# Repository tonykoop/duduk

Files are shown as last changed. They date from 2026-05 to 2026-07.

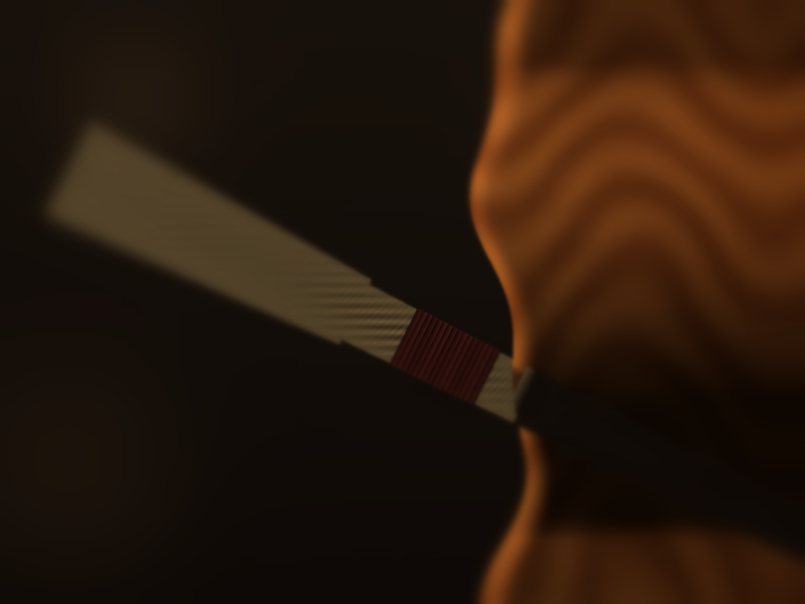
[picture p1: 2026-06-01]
images/macro/double-reed-bridle.png

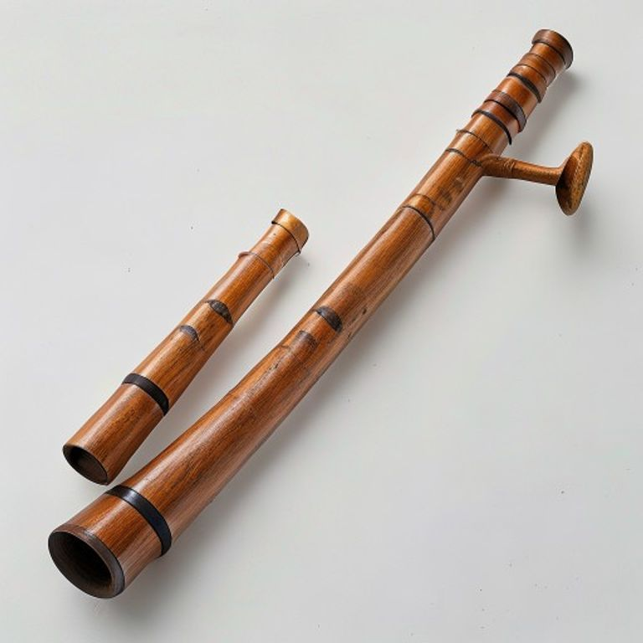
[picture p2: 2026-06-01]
images/hero-render.png

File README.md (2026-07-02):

# Duduk Family

Engineering documentation and parametric design table for the duduk family — Armenian double-reed apricot-wood instruments recognized as a UNESCO Intangible Cultural Heritage.

> **Scope.** This repository documents the geometry and acoustic physics of the duduk and its regional cousins (Turkish mey, Azerbaijani balaban, Georgian duduki) for workshop fabrication and study. It does not reproduce traditional Armenian reed-making craft or performance technique. All tuning predictions are marked **empirical** and require physical build and measurement. See [`resources.md`](resources.md) for full provenance notes.

**Status:** L1 concept packet — physical build and cultural review gates block L2 promotion. V5 surface added: family-spec.csv, visual-output-register.csv, cad/mcp-session-log.md. OpenSCAD smoke model present (pending_measurement authority). All dimensions measurement-required.

---

## Variants Documented

| Instrument | Region | Wood | Tone | Bore group |
|---|---|---|---|---|
| Duduk (*tsiranapogh*) | Armenia | Apricot | Warm, breathy, vocal | 0.315–0.551″ |
| Mey | Turkey | Plum / walnut | Bright, nasal | 0.394–0.630″ |
| Balaban | Azerbaijan | Mulberry | Reedy, penetrating | 0.315–0.551″ |
| Duduki | Georgia | Apricot/similar | Narrow, focused | 0.315–0.472″ |

20 keys documented (E3–B4 root) across all variants.

## Primary Build Target

**Armenian Duduk, A3 root** (traditional concert size)

| Parameter | Value | Status |
|---|---|---|
| Bore ID | 0.472″ / 12.0 mm | design input |
| Wall | 0.138″ / 3.5 mm | design input |
| OD | 0.748″ / 19.0 mm | calculated |
| Body length | ≈ 13.25″ / 33.7 cm | *EMPIRICAL* |
| Reed | Arundo donax, 3.90″ × 0.63″ | traditional |
| Wood | Apricot (preferred); walnut (alternate) | — |

Acoustic model: stopped cylindrical pipe, `f = c / (4·L_eff)`. Scale: A natural minor.

## Packet Contents

```
duduk/
├── README.md                   ← this file
├── duduk-design-table.xlsx     ← parametric design sheet (20 keys × 4 variants)
├── design.md                   ← acoustic model, hole schedule, family table
├── bom.csv                     ← bill of materials
├── sourcing.csv                ← supplier guidance
├── cut-list.csv                ← stock and machining sizes
├── validation.csv              ← dimensional and tuning checks
├── reed-bore-authority-gates.csv ← reed and bore promotion gates (R35b)
├── assembly-manual.md          ← step-by-step build instructions
├── supplier-rfq.md             ← RFQ template
├── visual-bom-brief.md         ← visual BOM spec
├── drawing-brief.md            ← drawing package spec
├── photo-shotlist.md           ← photo documentation plan
├── risks.md                    ← red-team risk register
├── resources.md                ← provenance, sources, cultural context
├── jig-decision.md             ← fixture decisions
├── explorer.html               ← studio explorer for packet review
├── drawings/
│   └── duduk-a3-section.svg   ← dimensioned longitudinal cross-section
├── cnc/
│   └── setup-sheet.md         ← lathe + drill-press operation plan
├── wolfram/
│   └── wolfram-starter.wl     ← Wolfram acoustic model package
├── site/
│   └── index.html             ← build-log static site
├── cad/                        ← conservative OpenSCAD smoke starter + CAD notes
├── evolution/                   ← evolution-pipeline Stage 0 intake: master manifest, design-intent, revision register (Gate A not yet run)
├── images/                     ← (placeholder — photos per photo-shotlist.md)
└── data/                       ← (placeholder — measured validation data)
```

## Quick Start

1. Read [`design.md`](design.md) for the acoustic model and empirical caveats.
2. Open `duduk-design-table.xlsx` (Sheet: Duduk Family) for the full parametric table.
3. Open [`explorer.html`](explorer.html) for a review-friendly index of the design files, validation gates, Wolfram source, print packet, site, and songbook material.
4. Order materials per [`sourcing.csv`](sourcing.csv) — **order 6+ reeds**; reed quality dominates the build outcome.
5. Follow [`assembly-manual.md`](assembly-manual.md) — body length is set empirically during reed fitting, not by formula.
6. Record all measured values in [`validation.csv`](validation.csv).
7. Review [`risks.md`](risks.md) — pay special attention to RISK-AC-01 (body length) and RISK-SC-02 (reed quality).
8. Before promoting any reed spec, bore dimension, calibrated body length, or fabrication DXF, clear the relevant rows in [`reed-bore-authority-gates.csv`](reed-bore-authority-gates.csv). The OpenSCAD smoke artifact in `cad/` and the dimensional starters in `design.md` are not fabrication authority until those gates pass.

## Cultural Heritage

The Armenian duduk (*tsiranapogh* — "apricot pipe") is a UNESCO Intangible Cultural Heritage instrument (2005). It is central to Armenian ceremonial music, played at weddings, funerals, and church services. The traditional knowledge of reed-making and performance practice is passed orally within the Armenian musical community.

This repository documents engineering geometry only. For the living musical tradition, listen to master players such as Djivan Gasparyan, and seek instruction from Armenian musicians.

See [`resources.md`](resources.md) for a full cultural context statement, source list, and public-release checklist.

## License

[CC BY 4.0](LICENSE) — engineering documentation. Cultural knowledge and traditional technique belong to the communities that carry them.

---

Part of the [tonykoop/instrument-maker](https://github.com/tonykoop/instrument-maker) catalogue · Generated with instrument-maker-v4.3

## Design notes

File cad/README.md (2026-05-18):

# Duduk CAD Starter

No build-ready CAD solids are included yet.
This lane ships a conservative OpenSCAD smoke artifact for visualization only:

- `duduk-openscad-smoke.scad`

Model the first body only after the A3-root prototype is measured with the reed actually used for tuning.

## Suggested Parameters

- `bore_id = 0.472 in`
- `body_od = 0.748 in`
- `body_length = measured after reed fit`
- `hole_positions = measured/tuned values from validation.csv`
- `reed_socket_depth = measured for selected reed`

## Notes

Keep the CAD file marked empirical until the reed/body calibration is complete. Duduk body length and hole behavior are reed-dependent, so workbook estimates should seed the model rather than freeze it.

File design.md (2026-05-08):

# Duduk Family — Design Document

**v4.3 Root-Mode Packet** | Generated 2026-05-08 | Status: DRAFT — Empirical Pending Build

> **Provenance Notice.** The duduk (dooduk / tsiranapogh) is an Armenian double-reed instrument recognized as a UNESCO Intangible Cultural Heritage (2005). This document is engineering reference material for study and workshop fabrication. It does not attempt to reproduce traditional performance technique, reed-making craft, or the tonal qualities achieved by master makers. Dimensions here are derived from published organological sources and cannot substitute for an instrument made by or studied with a traditional craftsperson. All acoustic predictions are first-estimate only and must be validated by physical build and tuning measurement. See `resources.md` for provenance, source citations, and cultural context.

---

## 1. Instrument Identity

| Field | Value |
|---|---|
| Instrument family | Duduk / Balaban / Mey (cylindrical-bore double-reed) |
| Primary variant documented | Armenian Duduk (*tsiranapogh* — apricot pipe) |
| UNESCO ICH status | 2005 (Armenian duduk and its music) |
| Acoustic class | Closed cylindrical aerophone (stopped pipe) |
| Excitation | Giant double reed (Arundo donax), sub-resonant to bore |
| Bore profile | Cylindrical (slight practical taper in traditional instruments — modeled as cylinder here) |
| Key naming convention | Instrument named root+3 semitones (e.g., "A3-root" instrument = "C4 duduk" by key name) |
| Design sheet | `duduk-design-table.xlsx` — Sheet: Duduk Family |
| Primary example | A3-root Armenian Duduk (bore 0.472″, OD 0.748″) |

---

## 2. Regional Variants

Four variants are documented in `duduk-design-table.xlsx`. All share the stopped-pipe acoustic model and 9-hole layout; they differ in bore diameter, wall thickness, reed dimensions, and traditional wood species.

| Variant | Wood | Tone character | Bore group (large/mid/small) |
|---|---|---|---|
| Armenian Duduk (*tsiranapogh*) | Apricot (*Prunus armeniaca*) | Warm, breathy, voice-like | 0.551″ / 0.472″ / 0.394″ / 0.315″ |
| Turkish Mey | Plum or walnut | Bright, nasal | 0.630″ / 0.551″ / 0.472″ / 0.394″ |
| Azerbaijani Balaban | Mulberry | Reedy, penetrating | 0.551″ / 0.472″ / 0.394″ / 0.315″ |
| Georgian Duduki | Apricot or similar | Similar to Armenian, narrower | 0.472″ / 0.394″ / 0.354″ / 0.315″ |

---

## 3. Governing Acoustic Model

### 3.1 Stopped Cylindrical Pipe

The duduk bore is modeled as a closed-open cylindrical pipe:

```
f_n = c · (2n − 1) / (4 · L_eff)      n = 1, 2, 3, …
```

- `f_1` (fundamental): `f = c / (4 · L_eff)`
- `c` = 343.0 m/s = 13,503.9 in/s at 20 °C / 68 °F
- Odd harmonics only → mellow, clarinet-like timbre

### 3.2 Effective Length

```
L_eff = L_body + L_reed_eff − δ_open_end
```

| Term | Symbol | Value (A3 primary) | Notes |
|---|---|---|---|
| Body tube length | `L_body` | **13.25″ / 33.7 cm** | *EMPIRICAL ESTIMATE — pending build* |
| Reed effective length | `L_reed_eff` | **1.95″ / 4.95 cm** | *~0.5 × physical reed — EMPIRICAL* |
| Open-end correction | `δ` | 0.142″ / 0.36 cm | `0.6 × r_bore` |
| Total acoustic length | `L_eff` | 15.35″ / 39.0 cm | c/(4×220 Hz) |

> **⚠ Empirical guard.** The reed effective length is the largest source of uncertainty. Traditional makers tune `L_body` empirically against the reed in use. The 0.5× estimate is a starting point only. Expect to trim the body or adjust the reed insert depth after first assembly. Record measured values in `validation.csv`.

### 3.3 End Correction (Workbook Formula)

From the embedded Wolfram spec in `duduk-design-table.xlsx`:

```mathematica
lDuduk[f_, bore_] := 343/(4 f) - 0.6 bore   (* SI units, bore = radius in meters *)
```

Where `bore` = bore radius (meters). This gives open-end correction = `0.6 × r_bore`.

### 3.4 Reed Sub-Resonance Requirement

The duduk double reed must be *sub-resonant* to the bore: the reed's natural vibration frequency must be higher than the bore's fundamental. If reed pitch < bore pitch, the instrument will not stable-oscillate on the fundamental.

```
f_reed_natural > f_bore_fundamental
```

- Players adjust reed pitch via the **bridle** (a band that constrains reed opening). Squeezing the bridle → reed natural frequency rises → instrument plays sharper.
- Reed pitch is controlled by bridle tightness, soaking duration, and temperature.
- **This is not predictable from geometry alone.** Reed behavior is EMPIRICAL.

Approximate reed cavity estimate (heuristic only):

```
f_reed_approx ≈ 0.6 × c / (2 × L_reed_physical)
```

For A3-root reed (3.9″ = 0.099 m): `f_reed_approx ≈ 0.6 × 343 / (2 × 0.099) ≈ 1040 Hz`
→ Well above 220 Hz bore fundamental. Sub-resonance condition likely satisfied. **Verify by ear on first build.**

### 3.5 Tone-Hole Positions — Simplified Cutoff Estimate (EMPIRICAL)

The table below uses a simplified acoustic cutoff approximation:
`position_from_bell ≈ L_acoustic(fundamental) − L_acoustic(hole_note)`

This is a **first estimate only**. Actual positions depend on tone-hole diameter, undercutting, and the tone-hole lattice interaction. All values require physical verification.

**A3-root Armenian Duduk — Hole Schedule (EMPIRICAL ESTIMATES)**

| Hole | Finger | Note | Freq (Hz) | Est. position from bell | Est. position from bell | Status |
|---|---|---|---|---|---|---|
| Root | all closed | A3 | 220.00 | — | — | model anchor |
| 1 | RH pinky | B3 | 246.94 | 1.67″ | 4.25 cm | *EMPIRICAL* |
| 2 | RH ring | C4 | 261.63 | 2.44″ | 6.20 cm | *EMPIRICAL* |
| 3 | RH middle | D4 | 293.66 | 3.85″ | 9.78 cm | *EMPIRICAL* |
| 4 | RH index | E4 | 329.63 | 5.10″ | 12.96 cm | *EMPIRICAL* |
| 5 | LH ring | F4 | 349.23 | 5.68″ | 14.42 cm | *EMPIRICAL* |
| 6 | LH middle | G4 | 392.00 | 6.73″ | 17.10 cm | *EMPIRICAL* |
| 7 | LH index | A4 | 440.00 | 7.67″ | 19.49 cm | *EMPIRICAL* |
| 8 | top front | B4 | 493.88 | 8.51″ | 21.61 cm | *EMPIRICAL* |
| 9 | thumb | C5 | 523.25 | 8.89″ | 22.59 cm | *EMPIRICAL* |

Scale: A natural minor (Aeolian) — A B C D E F G A.
Duduk repertoire frequently uses microtonal and modal inflections not captured here.

---

## 4. Primary Instrument Specification — Armenian Duduk, A3 Root

All dimensions marked **EMPIRICAL** are first estimates pending physical build and measurement.

| Parameter | Value | Status |
|---|---|---|
| Root note (all-closed fundamental) | A3 | design anchor |
| Duduk key name (root + 3 semitones) | C4 | convention |
| Frequency | 220.00 Hz | target |
| Bore ID | **0.472″ / 12.0 mm** | design input |
| Wall thickness | **0.138″ / 3.5 mm** | design input |
| Outer diameter | **0.748″ / 19.0 mm** | = bore + 2×wall |
| Body length (tube only) | **≈ 13.25″ / 33.7 cm** | *EMPIRICAL* |
| Reed insert socket depth | **≈ 0.50″ / 12.7 mm** | TBD |
| Reed physical length | 3.90″ / 99 mm | design input |
| Reed physical width | 0.63″ / 16 mm | design input |
| Reed material | Arundo donax (giant cane) | traditional |
| Wood species | Apricot (*Prunus armeniaca*) | traditional |
| Wood alternative | Walnut, mulberry, cherry | non-traditional |
| Tone holes | 9 (8 front + 1 thumb) | design |
| Hole diameter (estimate) | ≈ 0.25″ / 6.35 mm | *EMPIRICAL — adjust for ergonomics* |
| Bell end | open (no bell flare) | design |

---

## 5. Full Family Body Length Table — Armenian Duduk

All body-length values are **EMPIRICAL ESTIMATES** from the stopped-pipe formula minus estimated reed effective length. Physical reeds will vary; trim to tune.

| Key name | Root | Freq | Bore ID | OD | Reed L | Body est. | Body est. |
|---|---|---|---|---|---|---|---|
| Eb3 | E3 | 164.81 Hz | 0.551″ | 0.865″ | 4.70″ | **≈ 17.97″** | ≈ 45.6 cm |
| F3 | F3 | 174.61 Hz | 0.551″ | 0.865″ | 4.70″ | **≈ 16.82″** | ≈ 42.7 cm |
| Gb3 | Gb3 | 185.00 Hz | 0.551″ | 0.865″ | 4.70″ | **≈ 15.73″** | ≈ 40.0 cm |
| Ab3 | G3 | 196.00 Hz | 0.551″ | 0.865″ | 4.70″ | **≈ 14.71″** | ≈ 37.4 cm |
| A3 | Ab3 | 207.65 Hz | 0.551″ | 0.865″ | 4.70″ | **≈ 13.74″** | ≈ 34.9 cm |
| **C4** | **A3** | **220.00 Hz** | **0.472″** | **0.748″** | **3.90″** | **≈ 13.25″** | **≈ 33.7 cm** |
| Db4 | Bb3 | 233.08 Hz | 0.472″ | 0.748″ | 3.90″ | **≈ 12.39″** | ≈ 31.5 cm |
| Eb4 | B3 | 246.94 Hz | 0.472″ | 0.748″ | 3.90″ | **≈ 11.58″** | ≈ 29.4 cm |
| E4 | C4 | 261.63 Hz | 0.472″ | 0.748″ | 3.90″ | **≈ 10.81″** | ≈ 27.5 cm |
| F4 | Db4 | 277.18 Hz | 0.472″ | 0.748″ | 3.90″ | **≈ 10.09″** | ≈ 25.6 cm |
| G4 | D4 | 293.66 Hz | 0.394″ | 0.630″ | 3.50″ | **≈ 9.63″** | ≈ 24.5 cm |
| Ab4 | Eb4 | 311.13 Hz | 0.394″ | 0.630″ | 3.50″ | **≈ 8.98″** | ≈ 22.8 cm |
| A4 | E4 | 329.63 Hz | 0.394″ | 0.630″ | 3.50″ | **≈ 8.37″** | ≈ 21.3 cm |
| Bb4 | F4 | 349.23 Hz | 0.394″ | 0.630″ | 3.50″ | **≈ 7.80″** | ≈ 19.8 cm |
| B4 | Gb4 | 369.99 Hz | 0.394″ | 0.630″ | 3.50″ | **≈ 7.26″** | ≈ 18.4 cm |
| C5 | G4 | 392.00 Hz | 0.315″ | 0.511″ | 3.50″ | **≈ 6.77″** | ≈ 17.2 cm |
| Db5 | Ab4 | 415.30 Hz | 0.315″ | 0.511″ | 3.50″ | **≈ 6.29″** | ≈ 15.9 cm |
| D5 | A4 | 440.00 Hz | 0.315″ | 0.511″ | 3.50″ | **≈ 5.83″** | ≈ 14.8 cm |
| Eb5 | Bb4 | 466.16 Hz | 0.315″ | 0.511″ | 3.50″ | **≈ 5.40″** | ≈ 13.7 cm |
| E5 | B4 | 493.88 Hz | 0.315″ | 0.511″ | 3.50″ | **≈ 4.99″** | ≈ 12.7 cm |

**Bold row** = primary build target.

---

## 6. Design Notes and Open Questions

1. **Reed effective length (critical unknown).** The 0.5× factor is a rough heuristic. Traditional makers tune body length empirically with the reed in hand. Plan to build at +0.5″ over estimate and trim. Record final length in `validation.csv`.

2. **Bore taper.** Real Armenian duduks have a slight practical taper (wider at bell, narrower at reed end). This model treats it as perfectly cylindrical. Taper affects harmonic structure and tone color but has second-order effect on fundamental pitch. Treat as post-build refinement.

3. **Hole diameter and undercutting.** Tone-hole diameters affect cutoff frequency and cross-fingering possibilities. Starting estimate 0.25″; adjust for player hand size and desired response. Undercutting is a traditional technique to widen effective diameter without enlarging the surface opening.

4. **Scale accuracy.** The A natural minor scale holes give diatonic Armenian repertoire access. Traditional duduk playing uses extensive microtonal inflection via partial hole closure and embouchure — this cannot be captured in a fixed-hole layout.

5. **Reed sourcing.** Traditional Arundo donax reeds for duduk are specialty items. Source from Armenian or Middle Eastern music suppliers. Plan 4–6 reeds for initial testing (they break during adjustment). See `sourcing.csv` and `resources.md`.

6. **Wood species.** Apricot is the traditional and acoustic-preferred species but is not commonly available in US lumber yards. Walnut is a reasonable substitute (similar density, ρ ≈ 640–700 kg/m³ vs apricot ≈ 750 kg/m³). Will produce different tone color — do not claim tonal equivalence with traditional instruments.

7. **Authenticity scope.** This packet documents the geometry and physics of the duduk for workshop fabrication. Producing an instrument that approaches traditional performance quality requires additional study of Armenian reed-making and playing technique. See `resources.md`.

---

## 7. File Map

| File | Contents |
|---|---|
| `design.md` | This document |
| `duduk-design-table.xlsx` | Parametric design sheet (20 keys × 4 variants) |
| `bom.csv` | Bill of materials — A3-root Armenian build |
| `sourcing.csv` | Supplier recommendations |
| `cut-list.csv` | Stock and machining sizes |
| `validation.csv` | Tuning and dimensional check sheet |
| `assembly-manual.md` | Step-by-step build instructions |
| `supplier-rfq.md` | RFQ template for wood stock and reeds |
| `visual-bom-brief.md` | Visual BOM layout spec |
| `drawing-brief.md` | Drawing package spec |
| `wolfram/wolfram-starter.wl` | Wolfram model package |
| `drawings/duduk-a3-section.svg` | Dimensioned cross-section drawing |
| `cnc/setup-sheet.md` | CNC/lathe operation plan |
| `risks.md` | Red-team risk register |
| `resources.md` | Provenance, sources, cultural context |
| `jig-decision.md` | Fixture and jig decisions |
| `photo-shotlist.md` | Photo documentation plan |
| `site/index.html` | Build-log static site |

---

*Generated by instrument-maker-v4.3. All EMPIRICAL values require physical measurement before this packet is considered verified.*

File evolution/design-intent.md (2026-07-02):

# Design Intent — duduk rev A

- Master CAD: `cad/duduk-openscad-smoke.scad` (sha256: 5170423d3b3888ee2061eca8edef346e37ca6009c16b8273b03ef496fd137f22), driven by `duduk-design-table.xlsx` (sha256: e925b761a699e7a820cd903535036578964f6b31b38beb67a34fb77ca904b2b1)
- Function: Closed cylindrical stopped-pipe aerophone (Armenian duduk / Turkish mey / Azerbaijani balaban / Georgian duduki variants) excited by a giant double reed (Arundo donax), sub-resonant to the bore. 9-hole layout per variant; body length is an acoustic-model estimate pending reed-fit trim. UNESCO ICH (2005) — engineering reference only, not a claim of cultural/performance reproduction (see resources.md).
- Environment: hand-held wind instrument; wood body moves with humidity/oiling; reed behavior (and thus true body length) depends on the specific reed used.
- Target qty: 1 (prototype, A3-root Armenian variant). Deadline: TBD. Budget/unit ceiling: TBD.

## Critical dimensions (carry tolerances)

| Feature | Nominal | Tolerance | Why critical | Source |
| --- | --- | --- | --- | --- |
| Bore ID (A3 Armenian) | 0.472 in | ±0.005 in (validation.csv V-DIM-01) | tuning/timbre | family-spec.csv DUD-ARM-A3 (design_table_backed) |
| Body OD | 0.748 in | ±0.005 in (V-DIM-02) | wall strength vs. tone | duduk-design-table.xlsx (design_table_backed) |
| Wall thickness | 0.138 in | inspect for splitting (risks.md RISK-ST-01) | structural, thin-wall drilling risk | family-spec.csv (design_table_backed) |
| Body length (tube) | 13.25 in (estimate) | trim incrementally to tuned pitch (V-DIM-03) | intonation, reed-dependent | family-spec.csv (measurement_required) |
| Reed physical length | 3.90 in | ±0.10 in (V-DIM-04) | sub-resonance condition | bom.csv DUD-A3-002 (measurement_required) |
| Hole positions (1-9) | per simplified cutoff formula | ±30 cents initial, ±15 cents target (RISK-AC-03) | intonation, cannot un-drill | design.md governing model (measurement_required) |

## Incidental (free for DFM)

- Exterior finish choice (tung oil/wax), reed bridle material (thread vs. heat-shrink), cosmetic body taper/shaping outside the bore.

## Must-nots (DFM may never violate)

- Never drill side-force on the bore; drill-press only, perpendicular to bore axis (risks.md RISK-ST-01).
- Do not treat hole positions as final until each is drilled-and-tested in order from bell-end up, per RISK-AC-03.
- Do not publish or promote this packet as a cultural reproduction; it is workshop engineering reference only — cultural-review gates block L2 promotion (README, resources.md).
- Do not treat the four regional variants (Armenian/Mey/Balaban/Duduki) as interchangeable in public-facing text (RISK-AC/resources.md).
- Body length in family-spec.csv is an acoustic estimate, not a cut dimension — build over-length and trim per RISK-AC-01.

## Material intent

- Preferred: apricot wood (traditional, Armenian variant) or walnut/plum/mulberry per variant, per bom.csv.
- Acceptable subs: per bom.csv Source Category notes (specialty lumber/turning blank suppliers).
- Forbidden: film-forming finish on the bore (bom.csv DUD-A3-005 note); only food-safe bore oil.

## Stage status

Stage 0 intake complete 2026-07-01. Gate A (Alpha shop compile) NOT yet run — no concessions logged, nothing presented as shippable. Physical build and cultural review gates remain open per README; this intake does not change that.

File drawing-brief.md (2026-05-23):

# Drawing Brief — Duduk Family

**Drawing package:** Armenian Duduk, A3 root — v4.3 draft
**Date:** 2026-05-08
**File:** `drawings/duduk-a3-section.svg` (generated)

---

## Drawings Required

### DWG-01 — Body Cross-Section (primary)

- **View:** Longitudinal section through bore centerline
- **Scale:** 1:1 at A4/letter, or 1:2 if body won't fit at 1:1
- **Datum:** Bell end = 0 reference
- **Show:**
  - Outer profile (OD = 0.748″)
  - Bore (ID = 0.472″)
  - Wall thickness (0.138″ each side)
  - Tone hole positions (Holes 1–9, from bell) — marked EMPIRICAL
  - Tone hole diameters (~0.250″ est.) — marked EMPIRICAL
  - Reed socket depth (~0.500″) — marked TBD
  - Body length (≈ 13.25″ est.) — marked EMPIRICAL
  - Total acoustic length reference (15.35″ incl. reed eff.)
- **Title block:** Instrument, key, date, version, "EMPIRICAL — verify before drilling"
- **Material note:** Apricot / walnut, bore oil finish
- **Units:** Inches primary, cm secondary in parentheses

### DWG-02 — Hole Schedule (table drawing)

- **Format:** Table embedded in SVG or separate sheet
- **Columns:** Hole ID | Finger | Note | Freq (Hz) | Position from bell (in) | Position from bell (cm) | Dia (in) | Status
- **All positions flagged:** "EMPIRICAL ESTIMATE — measure and record actual in validation.csv"

### DWG-03 — Reed Geometry (reference)

- **View:** Side view of double reed showing overall length, tip width, shank width
- **Dimensions:** 3.90″ L × 0.63″ tip width, shank ≈ OD of bore
- **Note:** "Reed is not manufactured in-house. Dimensions shown for reference matching only."
- **Cross-section:** Flattened elliptical cross-section at tip; circular at shank

### DWG-04 — Family Comparison (optional, later)

- **View:** Side elevation of 4 variants (A3 Armenian, Turkish Mey, Balaban, Georgian) at same scale
- **Purpose:** Shows relative sizes across the family

---

## Drawing Standards

- All critical dimensions boxed
- Tolerance notes: ±0.005″ bore ID; ±0.005″ OD; hole positions ±0.020″ (first pass — adjust empirically)
- Revision block with date
- "DRAFT — v4.3 — Not for production without physical validation" watermark
- Title block: Instrument name | Key | Variant | Scale | Date | Drawn by

---

## Promotion Authority

Before any of the above drawings is promoted from EMPIRICAL/DRAFT to a fabrication-authority DXF, STEP, or shop-reviewed CAD release, check `reed-bore-authority-gates.csv`:

- DWG-01 bore ID, OD, wall, and body length are blocked by `BORE-GATE-001` (bore ID 3-point measurement), `BORE-GATE-002` (cylindricity / taper), and `BORE-GATE-003` (calibrated body length after empirical reed trim).
- DWG-01 reed socket depth and DWG-03 reed geometry are blocked by `REED-GATE-001` (reed dimensional spec), `REED-GATE-003` (reed effective length), and `REED-GATE-004` (reed stability under bridle).
- A full fabrication DXF or STEP is blocked by `BORE-GATE-004` until all preceding gates clear.

The existing `drawings/duduk-a3-section.svg` and the `cad/duduk-openscad-smoke.scad` smoke artifact remain draft/illustrative and do not satisfy these gates.

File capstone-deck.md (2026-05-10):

# Slide 1 - Duduk Family

L2 engineering packet for Armenian duduk and related mey, balaban, and duduki geometry.

# Slide 2 - Project Intent

Document a cautious shop prototype path for a reed-dependent heritage instrument while keeping empirical, cultural, and validation gaps explicit.

# Slide 3 - Cultural Scope

This packet covers engineering geometry only. It does not claim to reproduce Armenian reed-making, performance practice, or tonal tradition.

# Slide 4 - Governing Model

Stopped cylindrical pipe, `f = c/(4*L_eff)`, with reed effective length and open-end correction treated as empirical.

# Slide 5 - Primary Target

A3-root Armenian duduk body, 0.472 in bore ID, 0.748 in OD, approximate 13.25 in body length before reed calibration.

# Slide 6 - Packet Files

Design, BOM, sourcing, cut list, validation, assembly, drawing brief, SVG section, Wolfram starter, risks, resources, and site are present.

# Slide 7 - Manufacturing Plan

Turn and bore the body, fit reed socket, source multiple reeds, then tune body length and holes against the selected reed.

# Slide 8 - Validation

Validation centers on bore dimensions, reed fit, all-closed A3, every tone hole, reed stability, and cultural review before public release.

# Slide 9 - Risks

Top risks are reed effective length error, unverified hole positions, reed quality, and overclaiming cultural authenticity.

# Slide 10 - Sourceability

Apricot wood and duduk reeds require supplier verification. Current prices and availability are not checked.

# Slide 11 - Readiness

L2 private draft. Not public-ready until build photos, measured validation, and cultural review are complete.

# Slide 12 - Next Actions

Verify reed/wood sources, fit test reeds, build A3 body with trim allowance, populate validation.csv, then revisit CAD and public release.

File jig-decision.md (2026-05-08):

# Jig and Fixture Decision Log — Duduk Family

**v4.3** | 2026-05-08
Documents fixture choices for turning, boring, and hole-drilling operations on the duduk body.

---

## JIG-01 — Bore Drilling: Tailstock / Drill-Press Decision

**Question:** Should the bore be drilled on the lathe (tailstock-mounted drill) or on the drill press?

**Decision: Lathe (tailstock), using a long-series Forstner or D-bit.**

**Rationale:**
- The body blank is a cylinder ≤ 1.00″ dia × 16″ L. Holding it in a drill-press vise while drilling a 0.472″ bore 14″ deep is difficult to keep on-axis.
- On the lathe, the blank is already centered and rotating; the bit advances straight into the rotating stock. This is the conventional approach for cylindrical instrument bores.
- Drill-press boring requires a long-series bit, a reliable V-block or chuck, and very careful alignment — viable but harder than lathe boring for this geometry.

**Tooling selected:**
- **0.472″ long-series Forstner bit** (preferred for clean entry and flat bottom)
- Backup: **0.472″ D-bit or brad-point** for deeper runs where Forstner chatter may occur

**Setup notes:**
- Lathe speed: 300–500 RPM (slow for long boring)
- Back out every 0.5″ to clear chips
- Use cutting fluid (beeswax or dry lube on bit shank) to reduce heat buildup
- Check bore straightness with a light source at the open end after boring

**Verification:** After boring, measure bore ID with calipers at 3 points (near reed end, mid, near bell). Variation > 0.010″ = investigate re-centering.

---

## JIG-02 — Tone-Hole Drilling: V-Block Alignment Jig

**Question:** How to hold the finished cylinder for accurate perpendicular tone-hole drilling?

**Decision: V-block jig on drill press, with a registration stop for datum from bell end.**

**Rationale:**
- Tone holes must be perpendicular to the bore axis and at accurate positions along the body length.
- The finished body is a smooth cylinder — prone to rolling on a flat drill-press table.
- A V-block constrains the cylinder and keeps the drill axis perpendicular to the bore centerline.
- A registration stop (a wooden block clamped to the V-block) referenced from the bell end sets the datum for measuring hole positions.

**Jig construction:**
- V-block: 2×4 lumber with a 90° V-groove routed or cut to accept the 0.748″ OD. Groove depth ≈ 0.375″.
- Length: 12″ to support the full body.
- Stop block: a small wooden block clamped or screwed at the bell-end datum position. The bell face of the body registers against this stop.
- Clamp the cylinder with a soft strap or tape — do not over-clamp (crushes wood).

**Hole marking procedure:**
1. Seat body in V-block with bell end against stop.
2. Mark all 9 hole center positions along the top of the cylinder from bell-end datum (positions per `design.md` Section 3.5 — mark with Dykem + scribe).
3. Use a small center-punch or awl to create a dimple at each mark (prevents drill walk).
4. Drill pilot hole 0.1875″ first; open to 0.250″ in second pass.
5. Move stop registration only if re-measuring from bell — do not disturb mid-sequence.

**Verification:** After marking all centers, check spacing with calipers vs design table. Re-mark if any position is off by > 0.030″ before drilling.

---

## JIG-03 — Reed Shank Fitting: No Jig Required

**Question:** Does fitting the reed into the socket require a fixture?

**Decision: No dedicated jig — PTFE tape wrapping is hand-fitted.**

**Rationale:**
- The reed socket is simply the bore opening at the reed end of the body.
- Fitting is accomplished by wrapping the reed shank with PTFE plumber's tape until it seats firmly with a light press-fit.
- No precision fixture is needed; this is a common technique for woodwind reed fitting.
- The reed's position (depth of insertion) is adjusted empirically to tune the instrument.

**Procedure:**
1. Soak reed 15 minutes. Mount no PTFE yet.
2. Insert reed shank dry into bore top — feel how loose the fit is.
3. Wrap 3–5 layers of PTFE tape around the shank.
4. Re-insert — should seat firmly with light thumb pressure, no rocking.
5. Mark the seating depth with a pencil mark on the reed shank.
6. If too loose: add 1–2 more PTFE layers. If too tight: remove 1 layer.

---

## JIG-04 — Reaming / Bore Finishing: Dowel Sanding Mandrel

**Question:** How to sand the bore interior smooth after drilling without a reamer?

**Decision: Homemade sanding mandrel from a close-fitting wooden dowel.**

**Rationale:**
- A commercial adjustable reamer for 0.472″ is available but expensive for a one-off build.
- A dowel slightly undersized (0.440–0.460″ dia) wrapped with sandpaper is adequate for smoothing tearout after boring.
- This is suitable for finishing but not for enlarging the bore; all primary sizing must be done by the drill bit.

**Construction:**
- Turn or purchase a hardwood dowel 0.450″ dia × 12″ L.
- Wrap with 120/180/220/320 grit sandpaper (cut strips, spiral-wrap, secure with tape at ends).
- Chuck in lathe or spin by hand for lapping action.

**Verification:** Bore should feel smooth to a cotton swab drawn through it. No snagging or roughness.

---

## Jig Priority Summary

| Jig | Necessity | Build effort | When needed |
|---|---|---|---|
| JIG-01 Lathe setup | Required | Lathe chuck/centers (existing) | Before boring |
| JIG-02 V-block hole drill jig | Required | 1–2 hrs shop time | Before tone holes |
| JIG-03 PTFE fitting | Not a jig — hand technique | None | Reed fitting |
| JIG-04 Sanding mandrel | Recommended | 30 min | After boring |

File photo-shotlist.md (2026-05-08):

# Photo Shot List — Duduk Family Build

**Date:** 2026-05-08 | **Instrument:** Armenian Duduk, A3 root

Follow Tony's photo-pipeline standards: `docs/photo-pipeline.md` (in instrument-maker repo).
All photos for the build log must show actual instrument/parts — no stock images.

---

## Pre-Build

| Shot | Description | Setup | Notes |
|---|---|---|---|
| PB-01 | Raw wood blank | White card + natural light | Show grain direction; annotate OD |
| PB-02 | Reed (before fitting) | White card + macro lens | Show tip, bridle, shank; include 6" rule for scale |
| PB-03 | All materials laid out | Flat-lay on workbench | BOM shot: body blank, reeds, bridle, oils |

## During Build (In-Shop)

| Shot | Description | Setup | Notes |
|---|---|---|---|
| SH-01 | Blank mounted on lathe (before boring) | In-shop, tool visible | Show setup clearly |
| SH-02 | Boring operation (mid-drill) | In-shop | Capture chips, tooling |
| SH-03 | Bore after drilling — light through bore | End-on, backlit | Shows bore straightness (or lack thereof) |
| SH-04 | OD turning — tool at cut | In-shop | |
| SH-05 | Bore oiling — applying linseed | Close-up | Show application method |
| SH-06 | Hole marking — layout dye + scribe | Close-up | Show datum reference from bell end |
| SH-07 | Drilling first tone hole on drill press | In-shop | Show V-block jig setup |
| SH-08 | Reed fitting — PTFE wrap on shank | Close-up | |
| SH-09 | Tuning check — tuner reading fundamental | In-shop | Capture tuner display showing ~A3 |

## Finished Instrument

| Shot | Description | Setup | Notes |
|---|---|---|---|
| FIN-01 | Full instrument — front view | White card or neutral background | Horizontal, 3/4 angle |
| FIN-02 | Full instrument — side view | Same setup | |
| FIN-03 | Bell end close-up | Macro | Show bore and end grain |
| FIN-04 | Reed end with reed inserted | Macro | Show bridle and reed-bore junction |
| FIN-05 | All 9 holes visible | Angled | Light from side to show holes clearly |
| FIN-06 | Thumb hole — back side | Macro | |
| FIN-07 | Player holding instrument | In-use | Right-hand-down, left-hand-up conventional grip |
| FIN-08 | All family variants together (future) | Flat-lay | Once multiple keys are built |

## Details

| Shot | Description |
|---|---|
| DET-01 | Grain pattern — exterior close-up |
| DET-02 | Wall cross-section if a scrap was parted off |
| DET-03 | Reed tip — extreme macro showing cane cell structure |
| DET-04 | Bridle adjustment detail |

---

*Minimum for site/build-log: PB-03, SH-01, SH-07, SH-09, FIN-01, FIN-04, FIN-05.*
*Hero image for README: FIN-01.*

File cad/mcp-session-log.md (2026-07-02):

# MCP Session Log

V5 provenance — aligned with `tonykoop/instrument-maker` V5 build-packet standard.

No Claude Desktop MCP session was run for this packet. The smoke SCAD was
authored by hand from committed design-table and resources.md references.
No fabrication authority has been claimed for any output.

| session_id | tool | input_authority | outputs | role | authority_result | review_status | notes |
| --- | --- | --- | --- | --- | --- | --- | --- |
| 2026-05-17-scad-smoke-v1 | openscad | duduk-design-table.xlsx; design.md | cad/duduk-openscad-smoke.scad | cad_authoring | pending_measurement | unreviewed | Conservative smoke model with empirical seed values; geometry placeholder only; NOT fabrication authority. All bore and hole positions require measured values from validation.csv before any CAD/DXF authority is claimed. |
| fable-v5-refresh-2026-07-01 | claude-code (Fable 5) | duduk-design-table.xlsx, family-spec.csv | cad/duduk-openscad-smoke.scad, wolfram/duduk-wolfram-model.wl | packet_refresh | pending_measurement | self_checked | V5 refresh pass: existing L1 packet reviewed against baseline validator (0 failures, 2 pre-existing warnings unchanged); no dimension or authority changes made; existing smoke SCAD render-checked (openscad -o STL, exit 0); evolution/ Stage 0 intake added. Cultural-review and physical-build gates remain open per README. |

## V5 MCP Gate

Issue tonykoop/duduk#3 asks for a Claude Desktop OpenSCAD MCP session that
reads `duduk-design-table.xlsx`, writes `cad/duduk.scad`, and records the
session ID and provenance here. Until that session runs:

- `duduk-openscad-smoke.scad` is a hand-authored placeholder;
  authority_result remains `pending_measurement`.
- No STL, DXF, or fabrication output is claimed.
- `visual-output-register.csv` carries CAD-001 as `pending_measurement`.

When the MCP session runs, replace the 2026-05-17 row above with the real
session timestamp and Claude Desktop session ID, update `authority_result` to
`fabrication` only if the dimensions trace to reviewed design-table values,
and commit the new `cad/duduk.scad` alongside the updated log.

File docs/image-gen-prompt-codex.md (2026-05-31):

# Image Generation Prompt

Concept visualization only. Do not treat generated images as dimensional, tuning, CAD, DXF, or fabrication authority.

## Hero Prompt

Photorealistic studio product photograph of a finished Armenian duduk engineering prototype, a short cylindrical apricot-wood double-reed instrument with warm orange-brown grain, large flattened cane reed tied with a bridle, simple open finger holes, plain open foot, and understated workshop finish. Place it on a neutral cloth with several spare reeds and a small caliper as scale cues, clean studio background, soft directional studio lighting, three-quarter product-photography angle, about a 50mm lens, high detail, photorealistic.

## In-Context Prompt

Photorealistic scene of the duduk resting on a maker bench beside apricot wood blanks, reed cane, waxed thread, a tuner, and a validation notebook with no readable text. Natural warm light, respectful engineering-study atmosphere, no stage costume, the instrument presented as a workshop prototype honoring the duduk lineage without claiming traditional maker authority.

## Detail/Macro Prompt

Macro close-up of the duduk reed and socket: broad Arundo cane double reed with tied bridle, reed inserted into a smooth apricot-wood bore, subtle end grain, clean finger-hole edge behind it, shallow depth of field, soft raking light, photorealistic high detail.

## Negative / Avoid

Avoid cultural costume staging, logos, watermarks, readable text, modern clarinet mouthpieces, extra keys, impossible reed geometry, and fake maker signatures.

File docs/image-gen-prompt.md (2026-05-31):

# Image-Gen Prompts

Concept image only; not fabrication authority. Do not include cut-ready dimensions, hole locations, or toolpaths.

## Hero Prompt

A single Armenian duduk presented as a finished physical object: a slender straight cylindrical wooden pipe, roughly a forearm in length, with no bell flare — the bore end and the open playing end are both plain and untapered to the eye. The body is turned from warm apricot wood with a soft satin oil finish, fine close grain and gentle reddish-amber tone catching the light. A row of round tone holes runs along the front of the tube (eight in a line) with a single thumb hole on the underside, all simple drilled openings, no keys or metal hardware. At one end sits the instrument's signature feature: a large flat double reed of pale honey-colored Arundo donax cane, far wider and broader than an oboe reed, pressed into a wide blade tip, with a bridle band wound around its tapered shank where it seats into the wood socket. Clean neutral light-gray studio background, soft directional studio light raking gently across the grain, three-quarter product-photography angle, approximately 50mm lens, realistic scale cues, high detail, photorealistic, no text labels.

Avoid: no text, logos, watermarks, or fake maker marks; no dimension callouts or measurement lines; no keys, pads, or impossible mechanisms; no bell flare; reed must read as a wide flat cane double reed, not an oboe or clarinet reed.

IMPORTANT: This image is a concept visualization only. Do not include dimension lines, measurements, or fabrication specifications. The image is not authoritative for any physical build dimension.

## In-Context Prompt

The same apricot-wood duduk staged on a luthier's workbench in a small woodworking shop, resting on a soft cloth beside a few spare pale cane double reeds and a small bottle of bore oil. Warm natural window light from the side, sawdust and hand tools softly blurred in the background, shallow depth of field with the instrument's reed end in crisp focus. The mood is quiet and craft-centered, telling the story of a hand-finished traditional wind instrument awaiting first tuning. Concept visualization only.

Avoid: no text, logos, watermarks, or fake maker marks; no dimension callouts; no keys or impossible mechanisms; anatomically plausible hands if any are shown.

IMPORTANT: This image is a concept visualization only. Do not include dimension lines, measurements, or fabrication specifications. The image is not authoritative for any physical build dimension.

## Detail Prompt

Macro close-up of the duduk's signature double reed and its junction with the wooden body: the broad flat pale-honey Arundo donax cane blade tapering into a rounded shank, with a wound bridle band gripping the shank where it seats into the apricot-wood reed socket. Show the cane's fibrous surface and faint cell texture, the slight gloss of the bridle thread, and the warm grain of the wood meeting the cane. Raking side light to bring out texture, very shallow depth of field, high detail, photorealistic, no measurements.

Avoid: no text, logos, watermarks, or fake maker marks; no dimension callouts; no metal keywork; reed must read as a wide flat cane double reed.

IMPORTANT: This image is a concept visualization only. Do not include dimension lines, measurements, or fabrication specifications. The image is not authoritative for any physical build dimension.

## Family Group Prompt

A flat-lay of the documented duduk family laid side by side at consistent scale on a neutral light surface: the Armenian duduk in warm apricot wood, the Turkish mey with a slightly wider bore in plum or walnut wood, the Azerbaijani balaban similar in size to the Armenian instrument, and the narrower Georgian duduki. Each is a straight cylindrical oil-finished wooden pipe with a row of front tone holes, no bell flare, and a wide flat cane double reed seated at one end with a bridle band. The instruments vary subtly in length, bore width, and wood tone to show the family relationships. Soft even studio light, slight three-quarter overhead angle, high detail, photorealistic, concept visualization only.

Avoid: no text, logos, watermarks, or fake maker marks; no dimension callouts; no keys or impossible mechanisms; reeds must read as wide flat cane double reeds.

IMPORTANT: This image is a concept visualization only. Do not include dimension lines, measurements, or fabrication specifications. The image is not authoritative for any physical build dimension.

## Negative / Avoid

No text/logos/watermarks/fake maker marks; no dimension callouts; no keys, pads, or impossible mechanisms; no bell flare; reed must read as a wide flat cane double reed, not an oboe/clarinet reed; anatomically plausible hands if a player is shown.

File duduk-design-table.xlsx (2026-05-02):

Duduk Family — CNC Design Table
STOPPED PIPE: f = c/(4·L) — bore is half the length of equivalent open flute. UNESCO Intangible Heritage.
Root Note (all closed) |  | E 3 | F 3 | Gb 3 | G 3 | Ab 3 | A 3 | Bb 3 | B 3 | C 4 | Db 4 | D 4 | Eb 4 | E 4 | F 4 | Gb 4 | G 4 | Ab 4 | A 4 | Bb 4 | B 4
Piano Key |  | 32 | 33 | 34 | 35 | 36 | 37 | 38 | 39 | 40 | 41 | 42 | 43 | 44 | 45 | 46 | 47 | 48 | 49 | 50 | 51
Duduk Key Name | (root+3) | G3 | Ab3 | A3 | Bb3 | B3 | C4 | Db4 | D4 | Eb4 | E4 | F4 | Gb4 | G4 | Ab4 | A4 | Bb4 | B4 | C5 | Db5 | D5
Body Length (in)
Body Length (cm)
ARMENIAN DUDUK (ծիրdelays) — Apricot Wood, Warm/Soft
Bore ID (in) |  | 0.551 | 0.551 | 0.551 | 0.551 | 0.551 | 0.472 | 0.472 | 0.472 | 0.472 | 0.472 | 0.394 | 0.394 | 0.394 | 0.394 | 0.394 | 0.315 | 0.315 | 0.315 | 0.315 | 0.315
Wall Thickness |  | 0.157 | 0.157 | 0.157 | 0.157 | 0.157 | 0.138 | 0.138 | 0.138 | 0.138 | 0.138 | 0.118 | 0.118 | 0.118 | 0.118 | 0.118 | 0.098 | 0.098 | 0.098 | 0.098 | 0.098
Outer Diameter
Reed Length (in) |  | 4.7 | 4.7 | 4.7 | 4.7 | 4.7 | 3.9 | 3.9 | 3.9 | 3.9 | 3.9 | 3.5 | 3.5 | 3.5 | 3.5 | 3.5 | 3.5 | 3.5 | 3.5 | 3.5 | 3.5
Reed Width (in) |  | 0.75 | 0.75 | 0.75 | 0.75 | 0.75 | 0.63 | 0.63 | 0.63 | 0.63 | 0.63 | 0.5 | 0.5 | 0.5 | 0.5 | 0.5 | 0.5 | 0.5 | 0.5 | 0.5 | 0.5
Wood Species |  | Apricot | Apricot | Apricot | Apricot | Apricot | Apricot | Apricot | Apricot | Apricot | Apricot | Apricot | Apricot | Apricot | Apricot | Apricot | Apricot | Apricot | Apricot | Apricot | Apricot
TURKISH MEY — Plum/Walnut, Bright/Nasally
Bore ID (in) |  | 0.63 | 0.63 | 0.63 | 0.63 | 0.63 | 0.551 | 0.551 | 0.551 | 0.551 | 0.551 | 0.472 | 0.472 | 0.472 | 0.472 | 0.472 | 0.394 | 0.394 | 0.394 | 0.394 | 0.394
Wall Thickness |  | 0.177 | 0.177 | 0.177 | 0.177 | 0.177 | 0.157 | 0.157 | 0.157 | 0.157 | 0.157 | 0.138 | 0.138 | 0.138 | 0.138 | 0.138 | 0.118 | 0.118 | 0.118 | 0.118 | 0.118
Outer Diameter
Reed Length (in) |  | 3.9 | 3.9 | 3.9 | 3.9 | 3.9 | 3.5 | 3.5 | 3.5 | 3.5 | 3.5 | 3.1 | 3.1 | 3.1 | 3.1 | 3.1 | 3.1 | 3.1 | 3.1 | 3.1 | 3.1
Reed Width (in) |  | 0.67 | 0.67 | 0.67 | 0.67 | 0.67 | 0.55 | 0.55 | 0.55 | 0.55 | 0.55 | 0.47 | 0.47 | 0.47 | 0.47 | 0.47 | 0.47 | 0.47 | 0.47 | 0.47 | 0.47
Wood Species |  | Plum/Walnut | Plum/Walnut | Plum/Walnut | Plum/Walnut | Plum/Walnut | Plum/Walnut | Plum/Walnut | Plum/Walnut | Plum/Walnut | Plum/Walnut | Plum/Walnut | Plum/Walnut | Plum/Walnut | Plum/Walnut | Plum/Walnut | Plum/Walnut | Plum/Walnut | Plum/Walnut | Plum/Walnut | Plum/Walnut
AZERBAIJANI BALABAN — Mulberry, Reedy/Penetrating
Bore ID (in) |  | 0.551 | 0.551 | 0.551 | 0.551 | 0.551 | 0.472 | 0.472 | 0.472 | 0.472 | 0.472 | 0.394 | 0.394 | 0.394 | 0.394 | 0.394 | 0.315 | 0.315 | 0.315 | 0.315 | 0.315
Wall Thickness |  | 0.157 | 0.157 | 0.157 | 0.157 | 0.157 | 0.138 | 0.138 | 0.138 | 0.138 | 0.138 | 0.118 | 0.118 | 0.118 | 0.118 | 0.118 | 0.098 | 0.098 | 0.098 | 0.098 | 0.098
Outer Diameter
Reed Length (in) |  | 4.3 | 4.3 | 4.3 | 4.3 | 4.3 | 3.5 | 3.5 | 3.5 | 3.5 | 3.5 | 3.1 | 3.1 | 3.1 | 3.1 | 3.1 | 3.1 | 3.1 | 3.1 | 3.1 | 3.1
Reed Width (in) |  | 0.71 | 0.71 | 0.71 | 0.71 | 0.71 | 0.59 | 0.59 | 0.59 | 0.59 | 0.59 | 0.47 | 0.47 | 0.47 | 0.47 | 0.47 | 0.47 | 0.47 | 0.47 | 0.47 | 0.47
Wood Species |  | Mulberry | Mulberry | Mulberry | Mulberry | Mulberry | Mulberry | Mulberry | Mulberry | Mulberry | Mulberry | Mulberry | Mulberry | Mulberry | Mulberry | Mulberry | Mulberry | Mulberry | Mulberry | Mulberry | Mulberry
GEORGIAN DUDUKI — Similar to Armenian, Narrower
Bore ID (in) |  | 0.472 | 0.472 | 0.472 | 0.472 | 0.472 | 0.394 | 0.394 | 0.394 | 0.394 | 0.394 | 0.354 | 0.354 | 0.354 | 0.354 | 0.354 | 0.315 | 0.315 | 0.315 | 0.315 | 0.315
Wall Thickness |  | 0.138 | 0.138 | 0.138 | 0.138 | 0.138 | 0.118 | 0.118 | 0.118 | 0.118 | 0.118 | 0.098 | 0.098 | 0.098 | 0.098 | 0.098 | 0.079 | 0.079 | 0.079 | 0.079 | 0.079
Outer Diameter
Reed Length (in) |  | 4.3 | 4.3 | 4.3 | 4.3 | 4.3 | 3.5 | 3.5 | 3.5 | 3.5 | 3.5 | 3.1 | 3.1 | 3.1 | 3.1 | 3.1 | 3.1 | 3.1 | 3.1 | 3.1 | 3.1
Reed Width (in) |  | 0.67 | 0.67 | 0.67 | 0.67 | 0.67 | 0.55 | 0.55 | 0.55 | 0.55 | 0.55 | 0.47 | 0.47 | 0.47 | 0.47 | 0.47 | 0.47 | 0.47 | 0.47 | 0.47 | 0.47
Wood Species |  | Apricot/Similar | Apricot/Similar | Apricot/Similar | Apricot/Similar | Apricot/Similar | Apricot/Similar | Apricot/Similar | Apricot/Similar | Apricot/Similar | Apricot/Similar | Apricot/Similar | Apricot/Similar | Apricot/Similar | Apricot/Similar | Apricot/Similar | Apricot/Similar | Apricot/Similar | Apricot/Similar | Apricot/Similar | Apricot/Similar
STOPPED-PIPE ACOUSTIC MODEL
Acoustic Length (in) | c/(4·f)
Reed Eff. Length (in)
End Correction
DIATONIC SCALE (9 holes: 8 front + thumb)
Fundamental (Root) | Note | E 3 | F 3 | Gb 3 | G 3 | Ab 3 | A 3 | Bb 3 | B 3 | C 4 | Db 4 | D 4 | Eb 4 | E 4 | F 4 | Gb 4 | G 4 | Ab 4 | A 4 | Bb 4 | B 4
 | Frequency (Hz)
Hole 1 (RH pinky) | Note | Gb 3 | G 3 | Ab 3 | A 3 | Bb 3 | B 3 | C 4 | Db 4 | D 4 | Eb 4 | E 4 | F 4 | Gb 4 | G 4 | Ab 4 | A 4 | Bb 4 | B 4 | C 5 | Db 5
 | Frequency (Hz)
 | Diameter (in)
 | Dist. from End (in)
Hole 2 (RH ring) | Note | G 3 | Ab 3 | A 3 | Bb 3 | B 3 | C 4 | Db 4 | D 4 | Eb 4 | E 4 | F 4 | Gb 4 | G 4 | Ab 4 | A 4 | Bb 4 | B 4 | C 5 | Db 5 | D 5
 | Frequency (Hz)
 | Diameter (in)
 | Dist. from End (in)
Hole 3 (RH middle) | Note | A 3 | Bb 3 | B 3 | C 4 | Db 4 | D 4 | Eb 4 | E 4 | F 4 | Gb 4 | G 4 | Ab 4 | A 4 | Bb 4 | B 4 | C 5 | Db 5 | D 5 | Eb 5 | E 5
 | Frequency (Hz)
 | Diameter (in)
 | Dist. from End (in)
Hole 4 (RH index) | Note | B 3 | C 4 | Db 4 | D 4 | Eb 4 | E 4 | F 4 | Gb 4 | G 4 | Ab 4 | A 4 | Bb 4 | B 4 | C 5 | Db 5 | D 5 | Eb 5 | E 5 | F 5 | Gb 5
 | Frequency (Hz)
 | Diameter (in)
 | Dist. from End (in)
Hole 5 (LH ring) | Note | C 4 | Db 4 | D 4 | Eb 4 | E 4 | F 4 | Gb 4 | G 4 | Ab 4 | A 4 | Bb 4 | B 4 | C 5 | Db 5 | D 5 | Eb 5 | E 5 | F 5 | Gb 5 | G 5
 | Frequency (Hz)
 | Diameter (in)
 | Dist. from End (in)
Hole 6 (LH middle) | Note | D 4 | Eb 4 | E 4 | F 4 | Gb 4 | G 4 | Ab 4 | A 4 | Bb 4 | B 4 | C 5 | Db 5 | D 5 | Eb 5 | E 5 | F 5 | Gb 5 | G 5 | Ab 5 | A 5
 | Frequency (Hz)
 | Diameter (in)
 | Dist. from End (in)
Hole 7 (LH index) | Note | E 4 | F 4 | Gb 4 | G 4 | Ab 4 | A 4 | Bb 4 | B 4 | C 5 | Db 5 | D 5 | Eb 5 | E 5 | F 5 | Gb 5 | G 5 | Ab 5 | A 5 | Bb 5 | B 5
 | Frequency (Hz)
 | Diameter (in)
 | Dist. from End (in)
Hole 8 (top front) | Note | Gb 4 | G 4 | Ab 4 | A 4 | Bb 4 | B 4 | C 5 | Db 5 | D 5 | Eb 5 | E 5 | F 5 | Gb 5 | G 5 | Ab 5 | A 5 | Bb 5 | B 5 | C 6 | Db 6
 | Frequency (Hz)
 | Diameter (in)
 | Dist. from End (in)
Thumb Hole 9 | Note | G 4 | Ab 4 | A 4 | Bb 4 | B 4 | C 5 | Db 5 | D 5 | Eb 5 | E 5 | F 5 | Gb 5 | G 5 | Ab 5 | A 5 | Bb 5 | B 5 | C 6 | Db 6 | D 6
 | Frequency (Hz)
 | Diameter (in)
 | Dist. from End (in)
WOLFRAM CLOUD NOTEBOOK SPEC — DUDUK FAMILY
Armenian double-reed cylindrical-bore aerophone — closed-pipe acoustics with massive reed.
§1 — HISTORY, ETYMOLOGY & ORIGIN
Origin: Armenian highlands; some scholars trace to ~1500 BCE Urartu. Modern duduk is iconic of Armenian music, also played in Georgia, Azerbaijan, Iran (balaban), Turkey (mey) — all close cousins.
Duduk' from Armenian 'duduk' (pipe). UNESCO Intangible Cultural Heritage 2005. Made traditionally from apricot wood (tsiranapogh = apricot pipe).
Cousins: balaban (Iran/Azerbaijan), mey (Turkey), guan (China — slightly different lineage). All share the giant-cane double reed and cylindrical bore.
Wolfram items: GeoGraphics centered on Yerevan with halo of cousin instruments; TimelinePlot[{-1500, 400, 1900, 2005}→{Urartu, Christian Armenia, modern revival, UNESCO ICH}].
§2 — PHYSICS & ACOUSTICS
Stopped/closed-pipe: f = c/(4 L_eff). The huge double reed (~9–14 cm long, flattened cane) is acoustically closed at the player's lips. Cylindrical bore → odd-only harmonics → mellow, voice-like tone.
Reed resonance: the reed itself has its own pitch (~300–500 Hz fundamental). Reed must be 'sub-resonant' to bore (reed pitch > bore pitch) for stable sound. Players adjust reed by squeezing the bridle (the band that constrains reed opening).
Limited range → single octave (rarely 1 octave + minor 3rd via overblowing). Compensated by huge dynamic and timbral range: vibrato, growl, krunk (long sustained held tones).
Wolfram functions: NDSolve transmission-line model with reed-as-pressure-controlled-valve; Webster horn for slight bore taper (real duduks are not perfectly cylindrical); Periodogram + Spectrogram for vibrato analysis.
§3 — GEOMETRY & DESIGN MODEL
Body: cylindrical bore, ~28–40 cm depending on key. 9 holes (8 front + 1 thumb). Reed inserted into bridle at top; reed length adds to L_eff.
Sheet has 4 regional variants (Armenian, Iranian balaban, Turkish mey, …); 20 keys across the family. Use this sheet's design table for actual lengths.
Wolfram items: Manipulate L, bore, hole_x_i, reed_length; ParametricPlot3D bore + reed assembly; Graphics2D cross-section showing reed → bridle → bore.
§4 — MATERIALS & CORRECTIONS
Apricot (Prunus armeniaca): ρ ≈ 750 kg/m³, dense and stable, traditional choice. Modern alternatives: walnut, mulberry, ebony.
Reed: Arundo donax (giant cane), aged 2–3 years, soaked + flattened. Typical reed cost: $30–100, lifespan a few months of regular play.
Reed pitch tunes via bridle (band) tightness — squeezing the bridle raises reed resonance and makes the duduk play sharper and easier to overblow. Critical adjustment.
Temperature: warm reed = sharp; cold reed = flat and unstable. Players warm reed in mouth before playing.
§5 — BOM HOOK & MAP
SemanticImport["Flutes-AI.xlsx","Duduk Family"]; filter by regional variant; render reed sub-BOM with cane source notes.
Map: GeoGraphics Caucasus + Anatolia + Iranian plateau showing the duduk-balaban-mey trinity.
§6 — ANIMATED DIAGRAMS
Reed-bore coupling animation: Animate reed pressure ↔ bore pressure standing wave; show how reed-pitch-vs-bore-pitch ratio determines stable oscillation.
Bridle adjustment Manipulate: bridle tightness → reed natural f → bore stable f; visualize unstable / stable / sharp regions.
Standing-wave Animate: closed-end pressure anti-node at reed, open-end node at bell.
§7 — EXECUTABLE CELLS
lDuduk[f_,bore_]:=343/(4 f) - 0.6 bore (* m *)
duduk root note: keyName − 3 semitones (sheet convention)
reedPitch[L_,bore_]:= heuristic ~ 0.6 c/(2 L_reed) (* effective reed-cavity *)
§8 — DEPLOYMENT
CloudDeploy duduk-key-to-length calculator; APIFunction for full hole-position table given key + bore.
Wolfram functions: CloudDeploy, APIFunction, FormFunction, AudioCapture, Spectrogram, Export[ ,"CDF"|"PDF"].
WOLFRAM EXPLORATIONS — DUDUK FAMILY
Curated from the wolfram-notebooks-roadmap brainstorm — pick a row, file an issue, build the notebook.
Roadmap-inspired notebook ideas tailored to this sheet:
• Reed-Bore Coupling Stability Map — Reed pitch vs bore pitch ratio; map stable / unstable / sharp regions; predict bridle adjustment effect.
• Apricot Wood Acoustic Properties — E and ρ measurements; compare to walnut/mulberry; predict timbre shift at constant geometry.
• Vibrato + Krunk Synthesis — Long-tone synthesis with characteristic Armenian wide vibrato; AudioGenerator + tremolo + envelope shaping.
• Cultural Atlas: Caucasus Reed Trinity — GeoGraphics Armenia/Iran/Turkey for duduk/balaban/mey; phylogeny tree from common Sassanid root.
• Reed Aging Timeseries — Track reed pitch + responsiveness over months of play; recommend replacement schedule.

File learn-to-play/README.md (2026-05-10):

# learn-to-play / Duduk (A)

Starter songbook for the **A duduk** (Armenian double-reed) from the [`duduk`](https://github.com/tonykoop/duduk) build packet. Generated by the [`sheet-music`](https://github.com/tonykoop/sheet-music) skill.

The duduk is a double-reed instrument with a warm, vocal tone. Its character comes from
**glides** (slow portamento between notes) and **sustained drone-like phrases**.

Range: **G3 – C5** (approximately). Chromatic. The A duduk's fundamental is A3.

## Folder map
| Folder | Contents |
|---|---|
| `00-warmup-scales/` | Chromatic range walk, glide exercise, breath drill |
| `01-easy/` | Three classical Armenian folk melodies |
| `02-intermediate/` | Two modal pieces with glide ornaments |
| `03-original/` | *Ararat at Dusk* — Heifer Zephyr original |
| `fingering-charts.svg` | Full chromatic fingering chart, G3–C5 |

## Repertoire

### 01-easy
| Tune | Tradition |
|---|---|
| Grung (The Crane) | Trad Armenian (pre-1900) |
| Ov Sirun Sirun | Trad Armenian (pre-1900) |
| Hover My Dove (Hov Arek) | Trad Armenian (pre-1900) |

### 02-intermediate
| Tune | Tradition |
|---|---|
| Lorva Horovel | Trad Armenian plowing song (pre-1900) |
| Sari Gelin | Trad Armenian/Azerbaijani (pre-1900) |

### 03-original
**Ararat at Dusk** — 28-bar through-composed, A Phrygian, ♩=54.

## Notes on duduk notation
Grace notes in these ABC files indicate **glides** — slow portamento slides, not quick
ornamental grace notes. When you see `{X}Y`, slide slowly from X into Y over about half a beat.

## License
Arrangements MIT-licensed by Tony Koop / Heifer Zephyr. Traditional tunes: PD.

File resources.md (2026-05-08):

# Resources and Provenance — Duduk Family

**v4.3** | 2026-05-08

This document records the sources, cultural context, and provenance notes for the duduk design packet. It is required reading before making any part of this repository public.

---

## Cultural and Heritage Context

### Armenian Duduk (*tsiranapogh*)

The duduk — also written *dooduk* or *doodel* — is an Armenian double-reed aerophone with origins in the Armenian highlands. The name *tsiranapogh* translates literally as "apricot pipe" (*tsiran* = apricot, *pogh* = pipe/tube), reflecting the traditional material.

**UNESCO Recognition:** The "Armenian duduk and its music" was proclaimed a UNESCO Masterpiece of the Oral and Intangible Heritage of Humanity in 2005, and inscribed on the Representative List of the Intangible Cultural Heritage of Humanity in 2008.

The duduk is central to Armenian ceremonial, ritual, and expressive music. It is traditionally played in pairs — a solo *dudukahay* (duduk player) carries the melody while a second player sustains a drone. The sound is considered uniquely expressive of Armenian identity and is used at weddings, funerals, and religious ceremonies.

This packet documents the instrument's geometry for workshop study. **It is not a substitute for learning from a traditional Armenian musician or instrument maker.** The cultural knowledge embedded in traditional duduk-making — reed selection, reed-making by hand, tuning to the specific reed, and performance technique — is not captured here and cannot be derived from engineering documentation alone.

### Turkish Mey

The mey (also *balaban* in some Turkish regions) is the Turkish equivalent of the duduk, with a similar cylindrical bore and double reed. It is played widely in Anatolia, particularly in northeastern Turkey where Armenian and Turkish musical traditions historically overlapped. The mey has a slightly larger bore than the Armenian duduk (for comparable keys) and is described as brighter and more nasal in tone. It is a living performance tradition with active practitioners.

**Attribution note:** The mey and duduk share historical roots but have evolved as distinct cultural instruments within their respective traditions. They should not be conflated in public-facing text.

### Azerbaijani Balaban

The *balaban* (also spelled *bülbül* in some regions) is the Azerbaijani double-reed aerophone of the same family. It is widely used in Azerbaijani folk and classical mugham music. The Azerbaijani instrument uses mulberry wood and is associated with a penetrating, reedy tone quality. The name *balaban* is shared across multiple Turkic and Iranian traditions with related but distinct instruments.

**Attribution note:** The Armenian duduk, Turkish mey, and Azerbaijani balaban are distinct instruments within distinct living cultural traditions. Their shared physical form does not imply shared cultural identity.

### Georgian Duduki

The Georgian duduki is closely related to the Armenian duduk and is part of Georgian folk music traditions. It typically has a slightly narrower bore than the Armenian instrument. Georgian duduki music is an important part of Georgian polyphonic singing traditions, which are themselves UNESCO recognized.

---

## Organological Sources

The following sources informed the design table and physics documentation. Verify current availability; web sources change over time.

1. **Dournon, Geneviève.** "Hornbostel-Sachs Classification of Musical Instruments." *Galpin Society Journal* 34 (1981). (Classification reference — aerophone taxonomy.)

2. **Tsurtsumia, Rusudan, and Jordania, Joseph (eds.).** *Echoes from Georgia: Seventeen Arguments on Georgian Polyphony.* Nova Science Publishers, 2011. (Georgian context.)

3. **Petrova, Petya.** Various Armenian music and duduk resources published by the Armenian Musical Council and International Council for Traditional Music.

4. **UCLA Ethnomusicology Archive** — holdings on Armenian music and instrument documentation. (Reference for organological dimensions; specific accession numbers TBD.)

5. **Duduk.com and Armenian music retailer catalogs** — practical reed and instrument dimensions cross-referenced against design table.

6. **Coltman, J.W.** "Acoustics of the flute." *Physics Today* 21, no. 11 (1968). (Stopped-pipe acoustic model basis.)

7. **Fletcher, Neville H., and Rossing, Thomas D.** *The Physics of Musical Instruments.* 2nd ed. Springer, 1998. (Chapters on reed instruments and closed-pipe acoustics.)

> **Note:** The hole-position estimates in this packet are derived from simplified acoustic formulas, not from measured traditional instruments. They should not be cited as documentation of traditional duduk geometry.

---

## Design Scope Statement

**What this packet covers:**

- Engineering geometry (bore dimensions, body length estimates, hole schedule estimates) suitable for workshop fabrication and study.
- Acoustic physics of the stopped cylindrical pipe as an approximation of the duduk.
- Regional variant comparison across four closely related instrument families.
- Bill of materials and sourcing guidance for workshop construction.

**What this packet does NOT cover:**

- Traditional reed-making (a craft skill passed orally; requires years of practice).
- Performance practice, tuning to maqam/modal scales, vibrato, or ornamentation.
- The cultural, ceremonial, or spiritual significance of the instrument in its communities of origin.
- Historical or ethnomusicological accuracy of dimensions (all dimensions are first estimates from published sources and the stopped-pipe model; not derived from measured traditional instruments).
- Any claim that a workshop-fabricated instrument will sound like or be equivalent to an instrument made by a traditional Armenian craftsperson.

---

## Recommended Further Study

- Seek out a traditional Armenian duduk player or teacher for playing instruction.
- The Yerevan Conservatory and Armenian Cultural Associations in North America and Europe may have resources.
- Listen to master duduk players: Djivan Gasparyan is the most internationally known. His recordings document the full expressive range of the instrument.
- The *Songs of the Universe* and *I Will Not Be Sad in This World* albums (Djivan Gasparyan, ECM Records) are excellent reference recordings.

---

## Public-Release Checklist

Before making this repository public:

- [ ] Physical instrument has been built and measured (`validation.csv` complete)
- [ ] `risks.md` RISK-CU-01 and RISK-CU-02 have been addressed
- [ ] Provenance notes in README, `design.md`, and `site/index.html` have been reviewed
- [ ] At least one person with knowledge of Armenian musical traditions has reviewed the public-facing text for accuracy and appropriate framing
- [ ] No document claims tonal equivalence with traditional instruments
- [ ] All acoustic predictions are marked EMPIRICAL with measured values replacing estimates

**Current status: PRIVATE — pending physical build and cultural review.**

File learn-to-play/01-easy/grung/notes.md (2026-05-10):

# Grung (Կռունկ / The Crane)

**Tradition:** Trad Armenian; one of the oldest and most beloved duduk songs
**Public domain:** Yes — traditional folk song, pre-1900
**Arrangement:** A minor/Phrygian for A duduk. Range A3–E4.

## Context
*Grung* means "crane" in Armenian. The duduk's vocal, sighing tone is considered the
closest any instrument comes to the sound of longing and exile in Armenian culture.
This melody has been recorded by Djivan Gasparyan and is the quintessential duduk tune.

## Glide notation
`{B,}A,` = begin slightly above A3 and slide down into it. This is a smooth portamento,
not a quick grace note. Take about half a beat for each glide.

## Practice tip
Play it at ♩=50 or slower. This tune is not about speed — it's about breath and resonance.
Each phrase should sound like a human voice.

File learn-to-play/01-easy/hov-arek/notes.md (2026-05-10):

# Hov Arek (Ով Արեք / Hover My Dove)

**Tradition:** Trad Armenian folk song (pre-1900)
**Public domain:** Yes — traditional, pre-1929 (US)
**Arrangement:** D dorian for A duduk. Range A3–F4.

## Practice tip
The opening gesture `{A,}D` (glide from A3 up to D4) sets the tone for the whole tune.
Practice that glide until it's smooth and slow. The rest follows naturally.

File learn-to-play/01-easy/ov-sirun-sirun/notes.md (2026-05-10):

# Ov Sirun Sirun (Ով Սիրուն Սիրուն / Oh Beautiful)

**Tradition:** Trad Armenian folk song (pre-1900)
**Public domain:** Yes — traditional, pre-1929 (US)
**Arrangement:** A natural minor for A duduk. Range A3–A4.

## Practice tip
A gentle 3/4 — feel it as a slow waltz. The `{F}E` and `{B}A` grace notes are
descending glides: approach from above and fall into the note. Keep them slow and smooth.

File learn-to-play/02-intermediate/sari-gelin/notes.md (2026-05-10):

# Sari Gelin (Sarı Gəlin / Sarig Yar — Fair-Haired Bride)

**Tradition:** Trad Armenian/Azerbaijani folk song; origin disputed, pre-1900
**Public domain:** Yes — traditional folk melody, pre-1929 (US)
**Arrangement:** A natural minor/Phrygian for A duduk. Range A3–E4.

## Context
A deeply emotional song — associated with longing, loss, and the Caucasian landscape.
Played by duduk players across the region. The Phrygian b2 (Bb in A Phrygian) gives
it its characteristic aching quality.

## Practice tip
Every phrase in this tune is a glide. The `{X}Y` markings are guideposts, but in
practice you should be gliding almost continuously — let the pitch drift expressively.

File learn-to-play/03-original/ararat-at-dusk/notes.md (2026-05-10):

# Ararat at Dusk

**Composer:** Tony Koop / Heifer Zephyr (2025)
**License:** MIT — free to perform, record, arrange, and adapt
**Form:** Through-composed, 28 bars, ♩=54
**Instrument:** A duduk

## Story
Mount Ararat is visible from Yerevan but stands in Turkey — a presence that cannot be
reached. This piece sits in that quality: A Phrygian (the b2 is always there, unresolved),
the melody circling without arriving. Written for the duduk because no other instrument
holds longing the way a duduk does.

## Scale
A Phrygian: A Bb C D E F G. The Bb (half step above the root) is the instrument's
most characteristic interval. Use it deliberately.

## Practice tip
The long rests (`z4`) are part of the music. Do not fill them. Breathe during them,
but don't rush back in.

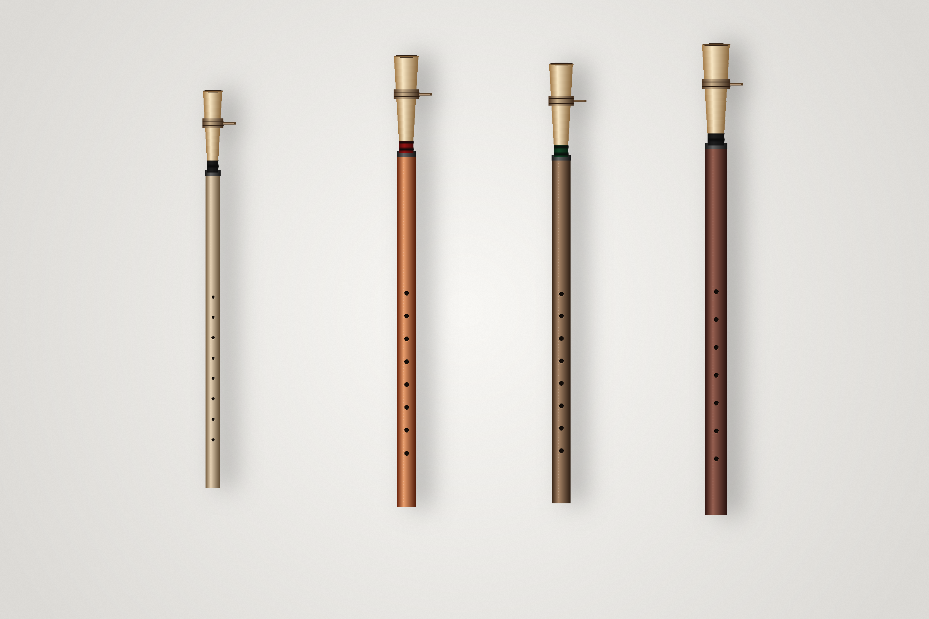
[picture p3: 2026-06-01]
images/family-group.png

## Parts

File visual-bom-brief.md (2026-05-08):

# Visual BOM Brief — Duduk Family

**For:** Graphic production of the visual bill of materials
**Instrument:** Armenian Duduk, A3 root (primary example)
**Date:** 2026-05-08

---

## Layout Spec

- **Format:** Single page, portrait or landscape, PDF-ready
- **Hero image:** Full instrument assembled with reed inserted — angled 3/4 view
- **Color palette:** Warm wood tones; white background; black text
- **Style:** Technical documentation — no decorative borders

## Table Structure

| Col | Content |
|---|---|
| # | Part ID (DUD-A3-001 etc.) |
| Image | Thumbnail photo or sketch of part |
| Description | Part name + brief description |
| Qty | Quantity |
| Unit | ea / oz / set |
| Material | Primary material |
| Est. Cost | USD each |
| Source | Category (specialty lumber, music supplier, hardware) |

## Part Thumbnails Needed

1. **Body tube (DUD-A3-001):** Photo/sketch of a cylindrical wood tube, showing bore end and bell end. Dimensions labeled: 0.748″ OD, 0.472″ bore, ~13.25″ body.
2. **Double reed (DUD-A3-002):** Photo of an Arundo donax duduk reed showing the wide flat tip, tapered shank, and bridle band. Annotate: tip, bridle, shank.
3. **Bridle (DUD-A3-003):** Close-up of bridle band on reed — thread-wound or rubber band style.
4. **Bore oil (DUD-A3-004):** Small oil bottle icon or photo.
5. **Exterior finish (DUD-A3-005):** Tung oil bottle.
6. **Reed insert wrap (DUD-A3-006):** Roll of PTFE tape.

## Notes

- All images must show actual parts, not mood boards.
- Mark reed image with note: "Reed source — Arundo donax, specialty supplier required"
- Add footer: "All costs estimated as of 2026-05-08. Verify before ordering."
- Add cultural note watermark or sidebar: "The duduk is a UNESCO Intangible Cultural Heritage instrument. Reed-making is a traditional craft skill not captured in this BOM."

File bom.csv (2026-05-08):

Part ID | Part Name | Description | Qty | Unit | Material | Dimensions (stock) | Est. Cost Each | Est. Total | Source Category | Notes
DUD-A3-001 | Body tube blank | Cylindrical body — Armenian Duduk A3 root | 1 | ea | Apricot wood (preferred) or walnut | 1.00" dia round × 16" L | 12.00 | 12.00 | Specialty lumber / turning blank | Apricot: specialty source req. Walnut: Woodcraft or similar. +2.75" over est. body for chuck allowance.
DUD-A3-002 | Reed (double — Arundo donax) | Giant cane double reed for A3 duduk | 4 | ea | Arundo donax (giant cane — aged) | 3.90" L × 0.63" W nominal | 20.00 | 80.00 | Specialty music supplier | Buy 4–6 for initial testing. Reeds break during fitting/adjustment. Source from Armenian music shops.
DUD-A3-003 | Bridle | Reed-clamping band (constrains opening) | 2 | ea | Synthetic or natural fiber cord / heat-shrink tubing | Approx. 0.75" wide × circumference of reed | 1.50 | 3.00 | Hardware / music supplier | Traditional: wound thread. Modern: heat-shrink or rubber band. Qty 2: one fitted + one spare.
DUD-A3-004 | Finish — bore | Food-safe bore oil (linseed or walnut oil) | 1 | oz | Linseed oil (boiled) or raw walnut oil | — | 3.00 | 3.00 | Hardware / grocery | Thin coats; flood bore and drain. Let cure 48 hrs between coats. 3 coats minimum.
DUD-A3-005 | Finish — exterior | Tung oil or wax finish | 2 | oz | Pure tung oil or beeswax + carnauba blend | — | 4.00 | 8.00 | Hardware / woodworking supply | Do not use film-forming finish on bore. Exterior: 2–3 coats wipe-on.
DUD-A3-006 | Reed insert wrap | Thread or tape to fit reed shank into socket | 1 | ea | PTFE plumber's tape or linen thread | — | 1.00 | 1.00 | Hardware | Wrap reed shank to achieve airtight fit in socket. Adjust wrap thickness for tuning.
DUD-A3-007 | Sandpaper — bore | Cylindrical bore smoothing | 1 | set | Sandpaper | 120/180/220/320 grit on dowel | 2.00 | 2.00 | Hardware | Wrap around a dowel slightly smaller than bore. Work progressively finer.
DUD-A3-008 | Marking fluid | Layout dye or pencil for hole center marking | 1 | ea | Dykem or felt-tip marker | — | 3.00 | 3.00 | Hardware / art supply | Mark hole centers from drawing. Verify with caliper before drilling.
 |  | TOTALS |  |  |  |  |  |  | 112.00 |  | All costs USD estimated; verify current pricing before ordering.
 |  | NOTES
 |  | Reed cost dominates BOM. Quality reeds from Armenian suppliers may be $30–100 each.
 |  | Apricot wood: if unavailable locally, consider Craft Supplies USA or specialist turning-blank suppliers.
 |  | All costs are estimates only — verify before purchasing. Last checked: 2026-05-08.

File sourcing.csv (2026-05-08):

Item | Supplier Category | Supplier Examples | SKU / Search Term | Notes | Status
Apricot wood turning blank (1" dia) | Specialty turning blank suppliers | Craft Supplies USA; Woodturners Catalog; Woodcraft (special order) | apricot turning blank 1" OR "apricot wood blank" | Apricot is not standard stock. May require special order or substitution. Check availability at time of order. | TBD — verify current availability
Walnut turning blank 1" dia (alternate) | General woodworking | Woodcraft; Rockler; local hardwood dealers | 1" dia walnut turning blank 16" | Good acoustic substitute. Widely available, lower cost. | Available
Mulberry turning blank (Balaban variant) | Specialty lumber, Asian hardwood suppliers | Hearne Hardwoods; Bell Forest Products | mulberry turning blank | Less common than walnut; check specialty hardwood dealers. | TBD — verify
Plum turning blank (Mey variant) | Specialty fruit-wood suppliers | Cook Woods; specialty orchard-wood sellers | plum wood turning blank | Very uncommon commercially. May need to source from orchard contacts. | TBD — verify
Arundo donax double reed (A3 duduk) | Armenian/Middle Eastern music suppliers | Duduk.com; Armenian music shops; eBay (search 'duduk reed') | duduk reed A OR "balaban reed" | Buy extra (4–6 for initial testing). Specify key if ordering pre-voiced. Reed quality is highly variable. | Critical — buy before build
Arundo donax raw cane (DIY reed blank) | Specialty reed suppliers | ReedMan; Lesher Oboe Reeds; oboe-supply shops | Arundo donax cane blanks / oboe cane | DIY reed making requires skill. Not recommended for first build. Buy pre-made reeds for initial testing. | Optional
Linseed oil (bore finish) | Hardware / grocery | Ace Hardware; Lowe's; Amazon | boiled linseed oil 1 qt | Boiled linseed oil dries faster. Raw works but takes longer. Use thin coats. | Available
Pure tung oil (exterior) | Hardware / woodworking | Woodcraft; Real Milk Paint Co. | pure tung oil — not ""tung oil finish""" | Must be 100% pure tung oil — not a blended 'tung oil finish' which contains varnish. | Available
PTFE plumber's tape | Hardware | Ace; Home Depot; Lowe's | PTFE thread seal tape | Use to seal reed shank into socket for airtight fit. Adjustable for tuning. | Available
Boron carbide abrasive cord OR drill bit set | Hardware, McMaster-Carr | McMaster-Carr; Harbor Freight | Step drill set 1/8" to 1/2" OR brad-point bit set | For tone holes: brad-point preferred for clean entry. Pilot hole + step-drill method. | Available

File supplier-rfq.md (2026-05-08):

# Supplier RFQ — Duduk Family Build

Date: 2026-05-08 | Quote needed for: Initial prototype — Armenian Duduk A3 root

---

## RFQ A — Wood Turning Blanks

**To:** [Craft Supplies USA / Woodcraft / Hearne Hardwoods / local hardwood dealer]

Please quote the following turning blanks:

| Item | Species | Form | Dimensions | Qty | Notes |
|---|---|---|---|---|---|
| A-1 | Apricot (*Prunus armeniaca*) preferred | Turning blank | 1.00″ dia × 16″ L minimum | 2 | If apricot unavailable, please quote walnut as alternate |
| A-2 | Walnut (*Juglans nigra*) alternate | Turning blank | 1.00″ dia × 16″ L minimum | 2 | Straight grain, no pith at center preferred |
| A-3 | Mulberry (for Balaban variant, optional) | Turning blank | 1.00″ dia × 16″ L minimum | 1 | Quote only if in stock |

**Finish:** None required — raw stock only.
**Grain:** Straight grain, vertical or radial orientation preferred. Quartersawn if available.
**Moisture content:** < 8% EMC preferred. Please confirm kiln-dried status.

---

## RFQ B — Double Reeds (Arundo donax)

**To:** Armenian music/instrument suppliers; specialty reed makers

Please quote the following:

| Item | Type | Key | Qty | Notes |
|---|---|---|---|---|
| B-1 | Duduk double reed — A3 (C4 key) | Armenian duduk — A (or specify Db4/C4 if different convention) | 6 | For instrument in key A3 root. Various suppliers use different key-naming conventions — please confirm what note the instrument sounds when all holes are open with this reed. |
| B-2 | Duduk double reed — assorted keys (optional) | One each: Bb3, G3, D4 root if available | 3 | Exploration set for family range study |

**Quality:** Pre-voiced preferred for initial testing. Raw/unvoiced acceptable if pre-voiced unavailable — will adjust bridle in-house.
**Material:** Arundo donax only (no synthetic reeds for this project).
**Bridle:** Include traditional bridle/band. Please note if bridle is adjustable or fixed.

---

## RFQ C — Finishing Supplies

Available from standard hardware suppliers (Ace, Home Depot, Amazon). No specialized RFQ required.

- Boiled linseed oil: 1 qt
- Pure tung oil (100% — not blended "tung oil finish"): 8 oz
- PTFE plumber's tape: 1 roll

---

## Contact Information

Tony Koop | tonykoop@gmail.com | [GitHub: tonykoop](https://github.com/tonykoop)

Please include: unit price, lead time, minimum order, shipping to ZIP [insert], and any notes on grain/quality of available stock.

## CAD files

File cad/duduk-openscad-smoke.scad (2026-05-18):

// Duduk conservative OpenSCAD smoke packet
// Source-only / geometry-smoke model for visual sanity checks.
// NOT build-ready CAD.

$fn = 96;

// EMPIRICAL seed values (from duduk packet docs). Validate and replace with measured values.
bore_id_in = 0.472;      // from workbook estimate
wall_in = 0.138;        // wall thickness placeholder
body_len_in = 13.25;    // acoustic seed only (A3 target)
reed_socket_len_in = 0.50;
reed_socket_inset_in = 0.02;
hole_diam_in = 0.12;

module bore_cylinder(len_in, bore_d_in, wall_in_) {
  difference() {
    cylinder(h = len_in, d = bore_d_in + 2 * wall_in_);
    translate([0, 0, reed_socket_inset_in])
      cylinder(h = len_in - reed_socket_inset_in * 2, d = bore_d_in);
  }
}

module reed_socket() {
  // Simplified placeholder to visualize reed seat geometry only.
  translate([0, 0, body_len_in - reed_socket_len_in])
    cylinder(h = reed_socket_len_in, d = bore_id_in * 1.08);
}

module hole_markers() {
  // Placeholder hole positions (from Wolfram estimates only).
  // Do not use for cutting; replace with tuned, measured values in validation.csv.
  for (i = [0:2:8]) {
    z = 0.80 + i * 0.75;
    translate([0, 0, z])
      cylinder(h = wall_in, d = hole_diam_in);
  }
}

// Axial shell
color([0.95, 0.93, 0.88])
bore_cylinder(body_len_in, bore_id_in, wall_in);

// End treatments
color([0.85, 0.83, 0.80])
  reed_socket();

color([0.4, 0.35, 0.18])
hole_markers();

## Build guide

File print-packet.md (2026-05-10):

# Duduk Family - Printable Shop Packet

**Readiness:** L2 private draft. Physical build, measured validation, and cultural review are pending.

## Critical Sequence

1. Source several reeds before final body tuning.
2. Bore and turn the A3-root body.
3. Fit the reed socket without air leaks.
4. Tune body length against the selected reed.
5. Drill and tune holes empirically.
6. Complete cultural review before public release.

## A3 Root Key Numbers

| Parameter | Value |
|---|---:|
| Root | A3, 220.00 Hz |
| Key name convention | root + 3 semitones |
| Bore ID | 0.472 in |
| OD | 0.748 in |
| Body length | approx. 13.25 in empirical |
| Reed | Arundo donax, approx. 3.90 in x 0.63 in |

## Warnings

- Reed behavior is the dominant unknown.
- Hole positions are empirical estimates.
- Do not claim traditional equivalence from this packet.
- Keep private until measured data and cultural review are complete.

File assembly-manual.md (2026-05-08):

# Duduk Assembly Manual — Armenian Duduk, A3 Root

**v4.3 Draft** | 2026-05-08 | All dimensions EMPIRICAL until measured and recorded in `validation.csv`

> **Safety.** No power tools beyond a drill press and lathe are required. Standard woodworking safety applies: eye protection, dust collection when turning/drilling wood.

---

## Before You Start

- Read `design.md` — understand the stopped-pipe model and why body length is empirical.
- Have 4–6 reeds on hand. You will likely break the first 1–2 during fitting and bridle adjustment.
- Soak the reed in warm water for 10–15 minutes before each work session.
- Set room temperature to 68 °F and humidity 40–55% RH if possible. Reed and wood behave differently in cold/dry conditions.

---

## Step 1 — Prepare Stock

1. Select a straight-grained blank: apricot (preferred) or walnut, 1.00″ dia × 16.0″ L minimum.
2. Inspect for cracks, knots, or runout. The bore must run parallel to the grain — center-pith blanks are risky (may crack). Prefer blanks where the pith is off-center or absent.
3. Mark the reed end (top) and bell end (bottom) with a permanent marker. The bell end is the narrower acoustic opening.

## Step 2 — Mount and True the Blank

1. Mount blank between centers on the lathe.
2. Turn a 0.75″ tenon on each end for chuck grip.
3. Re-chuck in 4-jaw chuck. True the OD: turn to 0.750″ (slightly over finished size).
4. Check runout at both ends: < 0.010″ TIR before boring.

## Step 3 — Drill the Bore

1. Mount a **0.472″ Forstner bit or D-bit** in the tailstock chuck.
2. Drill bore from the reed end (top) — the reed end will be trimmed last for tuning.
3. Use steady, low-RPM feed (300–500 RPM). Back out every 0.5″ to clear chips.
4. Drill full length of the blank. Check bore straightness with a light source at the bell end.
5. Sand bore lightly with 220 grit wrapped around a close-fitting dowel to remove tearout.

**⚠ Verify bore ID with calipers or bore gauge at 3 points before proceeding.**

## Step 4 — Turn the Outer Diameter

1. Re-chuck at bell end.
2. Turn OD to **0.748″** (bore + 2 × 0.138″ wall). Hold ±0.005″.
3. Traditional duduk profiles taper very slightly; for first build, keep parallel — taper can be added as refinement.
4. Sand exterior through 120/180/220/320 to finish.

## Step 5 — Cut to Rough Length

1. Part at approximately **14.0″** from the bell end (1.0″ longer than estimated body).
2. This extra length allows trimming during reed-fit tuning.
3. Face both ends square. Chamfer the bell end 30° × 0.010″ to prevent splitting.

## Step 6 — Reed Socket

1. The socket is the upper opening of the bore — no special machining for the first build.
2. After reed fit (Step 9), wrap the reed shank with PTFE tape until it seats firmly with an airtight seal.
3. **Stepped socket option (upgrade):** Turn a recess 0.020″ deeper × 0.500″ long at the reed end to give the reed shank a repeatable seat. Mark with Dykem before cutting.

## Step 7 — Bore Finish

1. Wipe bore dry and clean. Apply **boiled linseed oil** (first coat) via a cotton swab on a rod.
2. Flood bore — drain and wipe excess immediately.
3. Let cure **48 hours** at room temperature.
4. Apply second coat; cure again. Total: **3 coats minimum**.
5. Between coats: ream bore lightly with 320-grit to remove any raised grain.

## Step 8 — Exterior Finish

1. Apply **pure tung oil** to exterior with a lint-free cloth, thin coat.
2. Wipe off excess after 15 minutes (do not let pool or drip).
3. Cure 24 hours. Repeat for 2–3 coats.
4. Final: light buff with 0000 steel wool for a smooth matte finish.

## Step 9 — Reed Fitting and Initial Tuning

> **This is the critical empirical step.** The body length will be set by tuning the reed-fitted instrument to A3.

1. Soak reed in warm water for 15 minutes.
2. Wrap reed shank with PTFE tape (3–5 layers) until it seats in the bore top with light friction.
3. Insert reed into bore top until shank bottoms out or stops at ~0.5″ insertion depth.
4. Check airtightness: no hissing around the junction while blowing.
5. Play the fundamental (all holes closed). Adjust bridle tightness until stable oscillation.
6. Measure pitch with a chromatic tuner. Record in `validation.csv`.
7. **If sharp:** trim a small amount (0.050–0.100″) from the **bell end** and re-measure.
8. **If flat:** increase PTFE wrap to push reed slightly further out, or add insert-depth shim. If significantly flat, re-examine whether the bore was drilled full length.
9. Repeat until fundamental = A3 (220 Hz) ± 20 cents. Final tuning fine-adjusted by bridle and reed depth.

## Step 10 — Mark and Drill Tone Holes

> Hole positions are EMPIRICAL ESTIMATES. See `design.md` Section 3.5. Expect adjustment.

1. Lay the instrument on a V-block jig (see `jig-decision.md`).
2. Mark hole centerlines from the bell end using the hole-schedule in `design.md` (empirical estimates).
3. Use layout dye and a scribe or center punch.
4. Drill pilot holes: **0.1875″** brad-point through the wall.
5. Open to nominal **0.250″** with a brad-point or step drill.
6. Deburr inside the bore with a small carving tool or bore scraper.
7. Test each hole with the instrument before drilling the next: open holes sequentially from Hole 1 upward.
8. If a note is flat: move hole slightly toward bell end (enlarge bore-side position) or undercut.
9. If a note is sharp: plug with wax temporarily, measure, then re-drill slightly toward reed end.
10. Record all final hole positions in `validation.csv`.

## Step 11 — Final Check

- Complete all rows in `validation.csv`.
- Photograph all angles per `photo-shotlist.md`.
- Record reed, body length, and final hole positions for future reference.

---

*Duduk assembly is as much calibration as construction. Expect 2–4 hours of reed fitting and hole adjustment after the body is turned.*

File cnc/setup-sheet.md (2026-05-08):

# CNC / Lathe Operation Setup Sheet — Duduk A3 Root

**v4.3** | 2026-05-08
Pre-CAM operation plan for lathe turning and drill-press hole work.
This is NOT G-code. It is the human-readable plan used before any CAM work begins.

---

## Machine and Tooling Summary

| Machine | Operation | Required tooling |
|---|---|---|
| Wood lathe | Body turning, OD, boring | 4-jaw chuck; live center; 0.472″ long-series Forstner or D-bit; OD turning tool; parting tool |
| Drill press | Tone holes (9×) | Brad-point bits: 0.1875″ pilot + 0.250″ final; V-block jig; center punch |
| Hand tools | Reed fitting, finishing | PTFE tape; linseed oil brush; sandpaper 120→320 grit on dowel |

---

## Operation 1 — Stock Preparation

**Machine:** Hand tools / bench
**Datum:** N/A

| Step | Action | Check |
|---|---|---|
| 1.1 | Select blank: apricot or walnut, ≥1.00″ dia × 16.0″ L | Straight grain; no pith at center; kiln-dried |
| 1.2 | Measure moisture content | < 8% EMC — reject if higher |
| 1.3 | Mark reed end (top) and bell end (bottom) | Mark with permanent marker |
| 1.4 | Acclimate in shop ≥ 48 hrs before machining | Stable temperature 65–72°F |

**Release check:** Blank ≥ 16.0″ long, < 8% EMC, straight grain confirmed. ✓ → Proceed to Op 2.

---

## Operation 2 — Lathe: True and Chuck

**Machine:** Wood lathe
**Setup:** Between centers → re-chuck in 4-jaw

| Step | Action | Target | Check |
|---|---|---|---|
| 2.1 | Mount between centers | — | Centered, no wobble |
| 2.2 | Turn 0.75″ tenons at each end | 0.75″ dia × 0.75″ L | Concentric with blank axis |
| 2.3 | Re-chuck in 4-jaw at reed-end tenon | — | TIR < 0.010″ at bell end |
| 2.4 | Rough-turn OD to 0.780″ | 0.780″ ± 0.010″ | — |

**Release check:** TIR at bell end ≤ 0.010″. ✓ → Proceed to Op 3.

---

## Operation 3 — Lathe: Bore

**Machine:** Wood lathe (tailstock-fed)
**Datum:** Reed end (tailstock face)
**Workholding:** 4-jaw chuck at reed end; tailstock-mounted drill chuck

| Step | Action | Target | Notes |
|---|---|---|---|
| 3.1 | Mount 0.472″ long-series Forstner in tailstock chuck | — | Check bit is sharp and centered |
| 3.2 | Set lathe speed | 300–400 RPM | Slow for long boring |
| 3.3 | Bore through full blank length, backing out every 0.5″ | Through-bore | Clear chips every pass |
| 3.4 | Measure bore ID at 3 points | 0.472″ ± 0.005″ | Reject if > 0.010″ variation |
| 3.5 | Sand bore with 220/320 grit on mandrel | Smooth, no tearout | Light passes only |

**Release check:** Bore ID 0.472″ ± 0.005″ at 3 points. Light passes through without obstruction. ✓ → Proceed to Op 4.

---

## Operation 4 — Lathe: Finish OD and Part to Length

**Machine:** Wood lathe
**Datum:** Bell end (part to length from bell end)

| Step | Action | Target | Notes |
|---|---|---|---|
| 4.1 | Finish-turn OD | 0.748″ ± 0.005″ | Measure with calipers at 3 points |
| 4.2 | Sand exterior through 120/180/220/320 | Smooth matte | Work progressively |
| 4.3 | Part body at 14.0″ from bell end | 14.0″ ± 0.050″ | +0.75″ over estimated body for tuning stock |
| 4.4 | Face bell end square and chamfer 30° × 0.010″ | Clean end | Prevent end-grain splitting |
| 4.5 | Face reed end square | — | Leave rough until after reed tuning trim |

**EMPIRICAL NOTE:** Do NOT trim to final length yet. Final body length will be established in reed-fitting step.

**Release check:** OD 0.748″ ± 0.005″; rough length 14.0″; both ends faced. ✓ → Proceed to Op 5.

---

## Operation 5 — Bore and Exterior Finish

**Machine:** Bench / hand tools
**Sequence:** Bore oil BEFORE exterior finish

| Step | Action | Target |
|---|---|---|
| 5.1 | Apply boiled linseed oil to bore, 1st coat | Full flood; drain; wipe |
| 5.2 | Cure 48 hrs at 68°F | No tackiness |
| 5.3 | Apply 2nd bore coat | — |
| 5.4 | Cure 48 hrs | — |
| 5.5 | Apply 3rd bore coat | — |
| 5.6 | Apply pure tung oil exterior (3 thin coats, 24-hr cure each) | Matte, no runs |

**Release check:** Bore not tacky; exterior cured and smooth. ✓ → Proceed to Op 6.

---

## Operation 6 — Reed Fitting and Body Tuning Trim

**Machine:** Bench / hand tools + tuner

| Step | Action | Target |
|---|---|---|
| 6.1 | Soak reed 15 min in warm water | — |
| 6.2 | Wrap reed shank with PTFE tape (3–5 layers) | Firm friction fit in bore |
| 6.3 | Insert reed; adjust bridle | Stable oscillation on fundamental |
| 6.4 | Measure fundamental with tuner | A3 = 220 Hz target |
| 6.5 | If sharp: trim 0.050–0.100″ from bell end; re-measure | Trim until 220 Hz ± 10 cents |
| 6.6 | Record final body length in validation.csv | — |

**EMPIRICAL NOTE:** This step calibrates the body length. All subsequent hole positions reference the final bell-end datum after this trim.

**Release check:** Fundamental A3 ± 20 cents with stable oscillation. Body length recorded. ✓ → Proceed to Op 7.

---

## Operation 7 — Drill Press: Tone Holes

**Machine:** Drill press
**Datum:** Bell end of body (after tuning trim)
**Workholding:** V-block jig (see `jig-decision.md` JIG-02)

**Pre-drill setup:**
1. Register bell end against stop block on V-block jig.
2. Mark all 9 hole centers from bell datum (positions per `design.md` Section 3.5 — EMPIRICAL).
3. Verify spacing with calipers before drilling.
4. Center-punch all 9 positions.

**Drilling order: Hole 1 (nearest bell) → Hole 8 → then Thumb Hole 9**

| Hole | Note target | Est. position from bell | Pilot | Final dia |
|---|---|---|---|---|
| 1 (RH pinky) | B3 = 246.94 Hz | 1.67″ EMPIRICAL | 0.1875″ | 0.250″ |
| 2 (RH ring) | C4 = 261.63 Hz | 2.44″ EMPIRICAL | 0.1875″ | 0.250″ |
| 3 (RH middle) | D4 = 293.66 Hz | 3.85″ EMPIRICAL | 0.1875″ | 0.250″ |
| 4 (RH index) | E4 = 329.63 Hz | 5.10″ EMPIRICAL | 0.1875″ | 0.250″ |
| 5 (LH ring) | F4 = 349.23 Hz | 5.68″ EMPIRICAL | 0.1875″ | 0.250″ |
| 6 (LH middle) | G4 = 392.00 Hz | 6.73″ EMPIRICAL | 0.1875″ | 0.250″ |
| 7 (LH index) | A4 = 440.00 Hz | 7.67″ EMPIRICAL | 0.1875″ | 0.250″ |
| 8 (top front) | B4 = 493.88 Hz | 8.51″ EMPIRICAL | 0.1875″ | 0.250″ |
| 9 (thumb, back) | C5 = 523.25 Hz | 8.89″ EMPIRICAL | 0.1875″ | 0.250″ |

**Drill each hole, then test pitch before proceeding to the next.**

**Release check:** All 9 holes drilled; all pitches within ± 30 cents of targets. Record actual positions and measured pitches in `validation.csv`. ✓ → Packet complete.

---

## Pre-CAM Assumptions (explicit)

These assumptions must be verified before any CAM or G-code work:

1. Body stock is cylindrical and concentric to bore axis within 0.010″ TIR.
2. Bore is through the full length without obstruction.
3. Reed has been fitted and body trimmed to final tuned length before hole positions are marked.
4. Hole positions are empirical first estimates and will be adjusted after tuning — no CAM operation should treat them as final.
5. Tone hole diameters are nominal 0.250″ — actual diameter may be adjusted by undercutting.

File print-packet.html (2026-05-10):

# Duduk Family Print Packet

L2 private draft. Build validation and cultural review pending.

## A3 Root Target

Parameter | Value
Root | A3, 220.00 Hz
Bore ID | 0.472 in
OD | 0.748 in
Body length | approx. 13.25 in empirical

## Release Gate

Keep private until the instrument is built, measured, photographed, and the provenance text receives cultural review.

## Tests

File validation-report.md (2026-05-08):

# Validation Report — Duduk Family Packet

**v4.3 Verifier Pass** | 2026-05-08
**Mode:** Root-mode (Mode A) | **Packet:** `C:\Users\Tony\Documents\GitHub\duduk\`

---

## Verifier Summary

| Gate | Status | Notes |
|---|---|---|
| Packet completeness | ✅ PASS | All required root-mode files present |
| Acoustic model valid | ✅ PASS | Stopped-pipe formula applied correctly; empirical guards in place |
| Empirical markers | ✅ PASS | All unvalidated values clearly marked EMPIRICAL throughout |
| Risks documented | ✅ PASS | 12 risks across all 5 categories with verification tests |
| Resources/provenance | ✅ PASS | Cultural context, UNESCO attribution, variant attribution |
| Jig decisions | ✅ PASS | 4 jig/fixture decisions documented |
| Drawings present | ✅ PASS | `drawings/duduk-a3-section.svg` — longitudinal section |
| CNC/lathe plan | ✅ PASS | `cnc/setup-sheet.md` — 7 operations with release checks |
| Wolfram starter | ✅ PASS | `wolfram/wolfram-starter.wl` — physics model, Manipulate, audio, family table |
| Site present | ✅ PASS | `site/index.html` — build-log static page |
| README updated | ✅ PASS | Matches tongue-drum done-bar template; file map complete |
| Cultural review | ⚠ OPEN | Physical build not yet done; public-release checklist not complete |
| **Public-ready?** | ❌ NO | See recommendation below |

---

## File Inventory Check

### Required (root-mode) — all present ✅

| File | Found | Notes |
|---|---|---|
| `README.md` | ✅ | Updated with hero info, packet map, cultural notice |
| `duduk-design-table.xlsx` | ✅ | Existing — 20 keys × 4 variants, Wolfram spec embedded |
| `design.md` | ✅ | Acoustic model, family table, hole schedule, all EMPIRICAL-flagged |
| `bom.csv` | ✅ | 8 line items; reed sourcing note prominent |
| `sourcing.csv` | ✅ | 10 items; apricot and reed availability flagged TBD |
| `cut-list.csv` | ✅ | Body, socket, 9 tone holes; empirical hole positions noted |
| `validation.csv` | ✅ | 21 checks; all measured values = TBD |
| `assembly-manual.md` | ✅ | 11 steps; critical reed-fit/tuning step explicitly empirical |
| `supplier-rfq.md` | ✅ | Three RFQ sections (wood, reeds, finishing) |
| `visual-bom-brief.md` | ✅ | Layout spec with cultural note watermark requirement |
| `drawing-brief.md` | ✅ | 4 drawings specified |
| `photo-shotlist.md` | ✅ | 19 shots across pre-build, in-shop, finished, detail |
| `risks.md` | ✅ | 12 risks: 4 acoustic, 2 structural, 2 ergonomic, 2 supply, 2 cultural |
| `resources.md` | ✅ | Cultural context, variant attribution, sources, public-release checklist |
| `jig-decision.md` | ✅ | 4 decisions (lathe boring, V-block, reed fit, sanding mandrel) |
| `drawings/duduk-a3-section.svg` | ✅ | Longitudinal section with all holes, dimensions, title block |
| `cnc/setup-sheet.md` | ✅ | 7 operations with datum, tooling, workholding, release checks |
| `wolfram/wolfram-starter.wl` | ✅ | Stopped-pipe model, hole table, family table, Manipulate, audio, GeoMap |
| `site/index.html` | ✅ | Build-log page; cultural notice; all packet files linked |

### Optional / Placeholder — expected empty at this stage ✅

| Path | Status |
|---|---|
| `cad/` | Placeholder directory — SolidWorks files TBD post-build |
| `images/` | Placeholder — no instrument built yet |
| `data/` | Placeholder — no measured data yet |

---

## Quality Gate Checks

### 1. Physics model matches boundary conditions

**✅ PASS.** The duduk is a closed-open cylindrical pipe. The `f = c/(4·L_eff)` model is correct. The "closed" end is the reed (player's lip seal); "open" end is the bell. End correction `δ = 0.6·r_bore` is applied correctly at the open (bell) end only.

**Nuance noted and documented:** Real duduks have slight bore taper; the model treats the bore as perfectly cylindrical. This is appropriate for a first-build packet and is disclosed in `design.md` Section 6.

### 2. A4 = 440 Hz sanity check

**✅ PASS.** For the A4-root Armenian duduk (bore 0.315″):
- `L_acoustic = 343 / (4 × 440) = 0.195 m = 7.68″` ✓
- End correction = `0.6 × (0.315/2 × 0.0254) = 0.0024 m = 0.094″`
- Reed eff. = `0.5 × 3.5″ = 1.75″`
- Body est. = `7.68 - 0.094 - 1.75 = 5.83″` ✓ (plausible for a small duduk)

### 3. Empirical guard compliance

**✅ PASS.** Checked across all documents:
- `design.md`: body length, reed effective length, all 9 hole positions, hole diameter — all flagged EMPIRICAL
- `bom.csv`: costs marked "estimates only"
- `cut-list.csv`: hole positions flagged EMPIRICAL in notes column
- `validation.csv`: all `Measured` cells = TBD
- `assembly-manual.md`: Steps 9–10 explicitly call out empirical nature
- `drawings/duduk-a3-section.svg`: EMPIRICAL WARNING banner in drawing
- `site/index.html`: cultural heritage notice; PRIVATE status badge; all empirical values flagged

### 4. Reed treatment

**✅ PASS (for a pre-build packet).** The packet:
- Does not claim to predict reed behavior from geometry
- Explains the sub-resonance condition and bridle adjustment qualitatively
- Marks reed effective length factor (0.5×) as empirical and explains why it varies
- Instructs builder to fit reed before drilling holes (correct sequence)
- Instructs builder to test each reed before committing to hole drilling

**What remains open (post-build):** Reed resonance frequency measurement, bridle-tightness calibration, reed-depth vs. pitch empirical data. These are expected TBDs.

### 5. Risks — all categories covered

**✅ PASS.**

| Category | Count | Highest severity |
|---|---|---|
| Acoustic | 4 | High (RISK-AC-01 body length) |
| Structural | 2 | Medium |
| Ergonomic | 2 | Low |
| Supply chain | 2 | High (RISK-SC-02 reed quality) |
| Cultural | 2 | High (RISK-CU-01 overclaiming) |

All 12 risks have verification tests.

### 6. Cultural attribution

**✅ PASS (documentation).** Each variant (Armenian, Turkish, Azerbaijani, Georgian) has its own attribution paragraph in `resources.md`. The four variants are not conflated. UNESCO ICH status is correctly attributed (Armenian duduk, 2005).

**⚠ OPEN (review).** The public-release checklist in `resources.md` requires review by someone with knowledge of Armenian musical traditions before the repo goes public. This is a process gate, not a documentation deficiency.

### 7. Site cross-links

**✅ PASS.** `site/index.html` links to:
- GitHub repo
- instrument-maker catalogue
- `resources.md` (for cultural context)
- All major packet files listed in the files grid

### 8. CNC/operation plan pre-CAM assumptions

**✅ PASS.** `cnc/setup-sheet.md` explicitly lists 5 pre-CAM assumptions, including: "Tone hole positions are empirical first estimates and will be adjusted after tuning — no CAM operation should treat them as final." This is the correct posture for a pre-build packet on an empirically-tuned instrument.

---

## Remaining Findings (not auto-fixable)

These items require physical work or human judgment — not file edits:

| ID | Finding | Severity | Action |
|---|---|---|---|
| VF-01 | Physical instrument not yet built | High | Build the A3 Armenian prototype |
| VF-02 | All `validation.csv` measured values = TBD | High | Complete after build |
| VF-03 | `images/` directory is empty | Medium | Photograph per `photo-shotlist.md` |
| VF-04 | Cultural review not completed | High | Have provenance text reviewed before publishing |
| VF-05 | Reed effective length factor (0.5×) is an estimate | Medium | Measure actual body length after tuning; record in `validation.csv` |
| VF-06 | Hole positions unverified | High | Drill, test, and record in `validation.csv` |
| VF-07 | No SolidWorks CAD files | Low | `cad/` placeholder is acceptable for this stage |
| VF-08 | Capstone deck (.pptx) not generated | Low | Optional for a private/draft packet; generate before public release |
| VF-09 | Print packet (.pdf) not generated | Low | Optional for private/draft; generate before public release |

---

## Public vs. Private Recommendation

### Recommendation: **KEEP PRIVATE**

**Rationale:**

1. **No physical build.** All acoustic predictions are estimates. Publishing pre-build predictions as if they were measurements would misrepresent the instrument's actual behavior.

2. **Reed behavior unverified.** The most consequential unknown — how the body length interacts with the specific reed in use — has not been measured. This is the primary reason experienced duduk makers tune by ear, not by formula.

3. **Cultural review incomplete.** The duduk carries significant cultural weight as a UNESCO heritage instrument. The provenance text has not been reviewed by anyone with Armenian music knowledge. This is the right time to seek that review — before publication, not after.

4. **Hole positions are estimates, not measurements.** Publishing estimated hole positions as construction guidance risks producing instruments that don't play in tune. The positions must be physically validated and corrected before they are useful to another builder.

### Conditions for public release (from `resources.md` checklist):

- [ ] Physical instrument built and played
- [ ] `validation.csv` complete with measured values replacing all TBDs
- [ ] `images/` directory populated with shots per `photo-shotlist.md`
- [ ] Provenance text reviewed by someone with Armenian music knowledge
- [ ] No document claims tonal equivalence with traditional instruments
- [ ] All empirical predictions replaced with or supplemented by measured data

### Current packet fidelity

For a **pre-build study packet**, this is well above the threshold. The physics is correctly modeled, the empirical guards are in place, the cultural context is handled with care, and all the scaffold is ready to receive measured data. The packet earns:

**✅ Ready to build from.**
**❌ Not ready to publish.**

---

*Verifier pass completed: instrument-maker-v4.3 | 2026-05-08*

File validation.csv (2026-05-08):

Check ID | Category | Parameter | Target | Measured | Cents Error | Pass/Fail | Date | Instrument | Notes
V-DIM-01 | Dimensional | Bore ID | 0.472" ± 0.005" | TBD |  | TBD |  | DUD-A3-001 | Measure with bore gauge at 3 points (near reed end; midpoint; near bell)
V-DIM-02 | Dimensional | Body OD | 0.748" ± 0.005" | TBD |  | TBD |  | DUD-A3-001 | Measure at 3 points. Taper OK within ±0.010" over length.
V-DIM-03 | Dimensional | Body length (tube only) | Target TBD after reed fit | TBD |  | TBD |  | DUD-A3-001 | Record actual length after tuning trim. This IS the calibrated value.
V-DIM-04 | Dimensional | Reed physical length | 3.90" ± 0.10" | TBD |  | TBD |  | DUD-A3-002 | Measure from tip to shank base before fitting
V-DIM-05 | Dimensional | Reed physical width (max) | 0.63" ± 0.05" | TBD |  | TBD |  | DUD-A3-002 | Measure at widest point
V-ACOU-01 | Acoustic | Fundamental (all closed) | A3 = 220.00 Hz | TBD | TBD | TBD |  | DUD-A3 | Measure with electronic tuner (Korg OT-120 preferred). Tune reed bridle before measuring. Record temperature + RH.
V-ACOU-02 | Acoustic | Hole 1 open (B3) | 246.94 Hz | TBD | TBD | TBD |  | DUD-A3 | Record cents deviation from equal temperament. Traditional playing uses just intonation — deviation expected and acceptable.
V-ACOU-03 | Acoustic | Hole 2 open (C4) | 261.63 Hz | TBD | TBD | TBD |  | DUD-A3
V-ACOU-04 | Acoustic | Hole 3 open (D4) | 293.66 Hz | TBD | TBD | TBD |  | DUD-A3
V-ACOU-05 | Acoustic | Hole 4 open (E4) | 329.63 Hz | TBD | TBD | TBD |  | DUD-A3
V-ACOU-06 | Acoustic | Hole 5 open (F4) | 349.23 Hz | TBD | TBD | TBD |  | DUD-A3
V-ACOU-07 | Acoustic | Hole 6 open (G4) | 392.00 Hz | TBD | TBD | TBD |  | DUD-A3
V-ACOU-08 | Acoustic | Hole 7 open (A4) | 440.00 Hz | TBD | TBD | TBD |  | DUD-A3
V-ACOU-09 | Acoustic | Hole 8 open (B4) | 493.88 Hz | TBD | TBD | TBD |  | DUD-A3
V-ACOU-10 | Acoustic | Thumb hole open (C5) | 523.25 Hz | TBD | TBD | TBD |  | DUD-A3
V-ACOU-11 | Acoustic | Reed stability — all holes closed | No squeaking or instability at mf dynamic | TBD |  | TBD |  | DUD-A3 | Adjust bridle until stable oscillation. Record bridle position description.
V-ACOU-12 | Acoustic | Overblowing — lowest mode | Overblows to 3rd harmonic (a twelfth) at full pressure | TBD |  | TBD |  | DUD-A3 | Duduks typically don't overblow cleanly — limited range is characteristic. Note if any upper mode is accessible.
V-FIN-01 | Finish | Bore finish — cure | No tackiness; dry to touch | TBD |  | TBD |  | DUD-A3 | Check after 48-hr cure. Apply 3rd coat if still absorbing.
V-FIN-02 | Finish | Exterior — uniformity | No runs or bare patches visible | TBD |  | TBD |  | DUD-A3
V-CULT-01 | Cultural review | Provenance notes reviewed | Review resources.md before sharing publicly | TBD |  | TBD |  | — | Has the cultural context section been reviewed by someone with knowledge of Armenian music? Recommend: yes before making the repo public.
V-SAFE-01 | Safety | Reed fit — no air leak | No hiss audible around reed socket | TBD |  | TBD |  | DUD-A3 | Check with reed seated and playing. Adjust PTFE wrap if leaking.
 |  | MEASUREMENT CONDITIONS |  |  |  |  |  |  | Record: tuner model, temperature (°F), relative humidity (%), player
 |  | Temperature (°F): | Target: 68°F (20°C) | TBD
 |  | Relative Humidity (%): | Target: 40–55% RH | TBD
 |  | Tuner: | Korg OT-120 or equivalent chromatic tuner | TBD

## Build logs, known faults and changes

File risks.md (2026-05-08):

# Risk Register — Duduk Family

**v4.3 Red-Team Pass** | 2026-05-08
One risk entry per category minimum; each includes a verification test.

---

## 1. Acoustic Risks

### RISK-AC-01 — Reed effective length dominates tuning uncertainty

**Description:** The stopped-pipe formula assumes the reed acts as a pure acoustic closure. In practice, the reed cavity adds an effective length of approximately 0.5× physical reed length, but this varies significantly by reed stiffness, bridle tightness, and lip pressure. The resulting body-length estimate (13.25″ for A3) could be off by ±0.5–1.0″.

**Severity:** High — if body is cut too short, cannot be recovered; too long can be trimmed.
**Mitigation:** Build body at +0.75″ over estimate. Trim incrementally while checking tuning.
**Test:** After reed fitting, measure fundamental vs target (A3 = 220 Hz). Record deviation in `validation.csv`. Trim body ≤ 0.1″ per pass.

---

### RISK-AC-02 — Reed sub-resonance condition unverified

**Description:** The design assumes the reed's natural frequency (>1000 Hz estimated) is well above the bore fundamental (220 Hz). If a particular reed has unusually low natural frequency, stable oscillation on the fundamental may not occur.

**Severity:** Medium — manifests as squeaking, honking, or no stable tone.
**Mitigation:** Test each reed before drilling holes. Discard reeds that won't produce a stable fundamental with bridle adjustment.
**Test:** Fit reed on completed body (no holes drilled). Adjust bridle through full range. Observe: stable tone on fundamental = pass; unstable/squeaky = fail reed.

---

### RISK-AC-03 — Simplified hole-position model is insufficient

**Description:** Hole positions calculated from the simplified acoustic cutoff formula do not account for tone-hole lattice interaction, hole diameter, undercutting, or the influence of adjacent open holes. Errors of 0.2–0.5″ per hole position are plausible, increasing with higher holes.

**Severity:** Medium — each hole must be drilled, tested, and adjusted; cannot un-drill.
**Mitigation:** Drill in order from lowest (Hole 1, nearest bell) to highest. Test each note before proceeding. Mark positions with wax plug, adjust empirically.
**Test:** After drilling each hole: play note with that hole open, record pitch in `validation.csv`. Acceptable range: ±30 cents for initial pass (adjust by redrilling or undercutting to ±15 cents target).

---

### RISK-AC-04 — Bore non-cylindricity affects harmonic balance

**Description:** Long-bore drilling in wood often produces slight taper or bowing. A non-cylindrical bore alters the odd-harmonic relationship and may introduce even harmonics, changing the tone color away from the characteristic mellow duduk quality.

**Severity:** Low acoustic impact (slight taper); medium if extreme.
**Mitigation:** Use long-series drill bits, back out frequently, check bore straightness with light.
**Test:** After boring, shine flashlight through bore. Visible curvature = fail. Measure bore ID at 3 points; variation > 0.010″ = investigate.

---

## 2. Structural Risks

### RISK-ST-01 — Wall thickness sufficient for 0.472″ bore?

**Description:** Wall thickness = 0.138″ (3.5 mm) at bore 0.472″ OD 0.748″. This is a thin wall, typical of traditional instruments but challenging for initial drilling. Splitting risk is elevated near tone holes and at the reed socket end.

**Severity:** Medium — catastrophic if body cracks during drilling.
**Mitigation:** Use a V-block jig for tone-hole drilling. Do not apply side-force drilling — drill press only, perpendicular to bore axis. Anneal the reed socket end with gentle heat if cracking risk is high.
**Test:** Inspect all exterior surfaces with 10× loupe after each drilling operation. Any crack propagating from a hole edge = stop and assess. Thin-walled checks: measure OD and bore after turning to confirm ≥ 0.130″ wall at any point.

---

### RISK-ST-02 — Wood moisture content and cracking

**Description:** Wood that is not fully dried (≥8% EMC target) may crack as it acclimates to shop conditions. The thin wall and long bore create stress concentration.

**Severity:** Medium — cracks after finishing are cosmetically and acoustically damaging.
**Mitigation:** Confirm blank is kiln-dried (< 8% EMC). Acclimate blank in shop for ≥ 1 week before machining. Apply bore oil before exterior finish to equalize moisture uptake.
**Test:** Measure blank moisture with a pin-type meter before turning. Check for cracks after 2-week post-finish seasoning.

---

## 3. Ergonomic Risks

### RISK-ER-01 — Tone-hole spacing vs. hand reach

**Description:** The A3 root body is estimated at 13.25″ with holes spanning ~9″ of that length. Hole 1 (RH pinky) sits ~1.67″ from bell; Thumb 9 sits ~8.89″ from bell. The 7.2″ span between Hole 1 and Thumb 9 must be reachable by the intended player.

**Severity:** Low (traditional ergonomics are refined over centuries; layout should be playable for most adult hands).
**Mitigation:** Fit holes to a player with average hand size before committing to positions. Measure actual finger-to-finger spans.
**Test:** Mark estimated hole positions on a cardboard template. Have a player test reach before drilling.

---

### RISK-ER-02 — Reed mouth contact discomfort

**Description:** The large double reed (0.63″ wide) requires the player's lips to seal around it. Players new to double-reed instruments often develop lip fatigue or soreness. This is a playing technique issue, not a build defect.

**Severity:** Low (playing ergonomic, not instrument failure).
**Mitigation:** Note in README that duduk requires embouchure development. Recommend beginner players start with shorter practice sessions.
**Test:** N/A — document in README.

---

## 4. Supply Chain Risks

### RISK-SC-01 — Apricot wood availability

**Description:** Apricot wood turning blanks are not standard US inventory. Lead time may be 2–6 weeks; some suppliers may not carry it at all.

**Severity:** Medium (schedule impact; walnut substitute is acoustically viable).
**Mitigation:** Order apricot first; order walnut in parallel as backup. See `sourcing.csv`.
**Test:** Check supplier stock before committing build timeline. If apricot ≥ 4-week lead, proceed with walnut and note substitution in all docs.

---

### RISK-SC-02 — Reed quality and consistency

**Description:** Commercially available duduk reeds vary widely in quality, voicing, and consistency. A poorly voiced reed may prevent stable oscillation regardless of body quality.

**Severity:** High (no instrument without working reed).
**Mitigation:** Order 6+ reeds. Plan for 1–2 to break during fitting. Allow time to find a reed that works with the specific body built.
**Test:** Test each reed on a reference commercial duduk if available, before using on the new body. Reject reeds that are cracked, unevenly scraped, or won't oscillate.

---

## 5. Cultural and Authenticity Risks

### RISK-CU-01 — Overclaiming authenticity or performance equivalence

**Description:** This document provides engineering geometry of the duduk form. It does not capture: traditional Armenian reed-making technique, oral tuning traditions, performance practice (vibrato, krunk, ornaments), or the social/cultural context of the instrument. Public-facing documentation that implies these are captured risks misrepresenting Armenian cultural heritage.

**Severity:** High (reputational and cultural harm risk if overclaimed).
**Mitigation:** All documents include provenance notices (see `resources.md`). README explicitly states this is a workshop fabrication study, not a cultural reproduction. Do not publish without cultural context review.
**Test:** Read all public-facing documents (README, `resources.md`, `site/index.html`). Any sentence that implies "this is a traditional Armenian duduk" or "this instrument sounds like..." without empirical qualification = revise before publishing.
**Recommendation:** Keep repo PRIVATE until (a) physical build complete, (b) tuning validated, (c) provenance notes reviewed by someone with Armenian music knowledge.

---

### RISK-CU-02 — Incorrect or incomplete cultural attribution

**Description:** The design table covers Armenian duduk, Turkish mey, Azerbaijani balaban, and Georgian duduki. These instruments exist within living cultural traditions that have distinct identities. Conflating them or misattributing origin risks inaccuracy.

**Severity:** Medium.
**Mitigation:** `resources.md` documents each variant separately with distinct attribution. Do not treat the variants as interchangeable in public-facing text.
**Test:** Review `resources.md` — each variant should have its own attribution paragraph. Any paragraph that conflates Armenian and Azerbaijani or Turkish instruments without noting the distinction = revise.

---

## Risk Summary

| ID | Category | Severity | Pre-build action required? |
|---|---|---|---|
| RISK-AC-01 | Acoustic | High | Yes — build at +0.75″, plan trim |
| RISK-AC-02 | Acoustic | Medium | Yes — test reed before drilling holes |
| RISK-AC-03 | Acoustic | Medium | Yes — drill holes incrementally |
| RISK-AC-04 | Acoustic | Low | Yes — check bore cylindricity |
| RISK-ST-01 | Structural | Medium | Yes — V-block jig for hole drilling |
| RISK-ST-02 | Structural | Medium | Yes — confirm kiln-dried stock |
| RISK-ER-01 | Ergonomic | Low | Recommended — template test |
| RISK-ER-02 | Ergonomic | Low | No — document in README |
| RISK-SC-01 | Supply | Medium | Yes — order materials 4+ weeks out |
| RISK-SC-02 | Supply | High | Yes — order 6+ reeds |
| RISK-CU-01 | Cultural | High | Yes — keep private until review |
| RISK-CU-02 | Cultural | Medium | Yes — review resources.md |

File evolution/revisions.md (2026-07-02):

# Revision Register — duduk

| Rev | Date | Parent | Delta | Downstream artifacts invalidated |
| --- | --- | --- | --- | --- |
| A | 2026-07-01 | — | Stage 0 intake of current masters (cad/duduk-openscad-smoke.scad + duduk-design-table.xlsx). | none (no alpha/beta/production artifacts exist yet) |

Stage 0 only. Gate A has not been run; no Alpha compiles, vendor quotes, or production lock exist for this product. Cultural-review and physical-build gates (README) remain open independent of this intake.

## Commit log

2026-05-02 Initial scaffold: Duduk Family
    [duduk-design-table.xlsx]
2026-05-18 Add duduk B1 OpenSCAD smoke artifact (#4)
    [duduk-openscad-smoke.scad]
2026-05-20 Add reed-bore authority gates (REED-GATE-001..004, BORE-GATE-001..004) (#6)
    Refs #1
    The duduk packet has a measurement protocol (validation.csv with
    V-DIM-01..05 and V-ACOU-01..12) and a risk register (risks.md with
    RISK-AC-01..04 and RISK-SC-02), but no machine-readable file blocking
    promotion of reed dimensional spec, bore dimensions, calibrated body
    length, or a fabrication DXF until measurement and risk-verification
    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
    [reed-bore-authority-gates.csv]
2026-05-29 Add V5 packet surface: family-spec, visual register, mcp log (Refs #1, Refs #3) (#7)
    Adds family-spec.csv with 5 variant rows (Armenian, Mey, Balaban, Duduki;
    all measurement_required authority from duduk-design-table.xlsx).
    Adds visual-output-register.csv registering smoke SCAD (pending_measurement),
    section SVG (concept_only), and Wolfram starters (reference_only).
    Adds cad/mcp-session-log.md documenting the smoke SCAD as hand-authored
    pending_measurement placeholder with a V5 gate for future Claude Desktop
    OpenSCAD MCP session (issue #3).
    Updates README status to L1 concept packet with V5 surface.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
    [family-spec.csv, visual-output-register.csv]
2026-05-31 Add image-gen concept prompt; wire explorer images
2026-05-31 Add deployable Wolfram interactive model + wire live explorer embed
    Model returns a bare Manipulate (SaveDefinitions->True); CloudDeploy'd Public.
2026-06-21 Wire 3 rendered concept image(s) into explorer gallery
2026-07-02 V5 packet refresh: provenance row, evolution intake
    Validator: python3 validate_v5_packet.py . --slug duduk -> 0 failures, 2 pre-existing warnings unchanged (smoke-scad authority WARN, SVG fabrication-language WARN). No dimension or status changes; L1 concept packet level kept as-is. Added evolution/ Stage 0 intake (manifest, design-intent, revisions) and one provenance row documenting this refresh pass. Existing cad/duduk-openscad-smoke.scad kept and render-checked (openscad -o STL, exit 0).
